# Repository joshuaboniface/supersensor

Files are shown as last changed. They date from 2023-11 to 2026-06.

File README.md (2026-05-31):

# SuperSensor v3.x

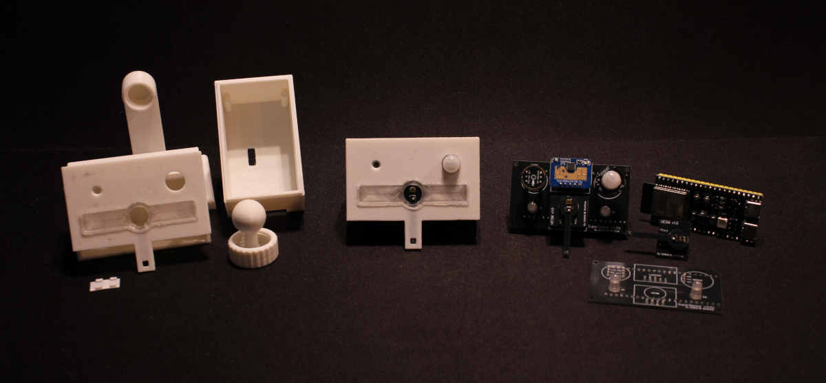
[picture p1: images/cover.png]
SuperSensor


The SuperSensor is a free-and-open-source multi-sensor array with voice control capabilities using ESPHome, designed for use with Home Assistant.

Inspired heavily by the EverythingSmartHome Everything Presence One sensor and the HomeAssistant "$13 Voice Assistant" project, its goals are to track human presence in a room using both millimetre-wave radar and passive infrared, provide voice control capabilities for Home Assistant Assist pipelines via a microphone and coloured feedback LEDs, and provide data on the room environment including temperature, humidity, VOC, eCO2, NOx, and light levels. It's based on the ESP32-S3 platform running ESPHome, providing plenty of power for all the demands of this sensor array.

If you want to automate your home and life with Home Assistant, the SuperSensor is the perfect tool for the job.

This branch is for version 3.x of the SuperSensor, the current version, based on the ESP32-S3 microcontroller and using our custom Unified Environment Sensor Module (UESM). For previous versions based on the ESP32 microcontroller, please see the [v2.x](https://github.com/joshuaboniface/supersensor/tree/v2.x) and [v1.x](https://github.com/joshuaboniface/supersensor/tree/v1.x) branches. Users new to the project should use v3.x exclusively as it has numerous improvements over the previous versions, even though it is more complicated to build.

For more information, please see the following:

 * The [blog post on v3.0](https://www.boniface.me/posts/the-supersensor-3.0)
 * The [introduction video]()
 * The PCB design details [in `board/`](board/) and on [OSHWLab](https://oshwlab.com/joshuaboniface/supersensor-3-0)
 * The case design details [in `case/`](case/) and on [TinkerCAD](https://www.tinkercad.com/things/gx66mJQMgR6)
 * Calibration and configuration instructions [in `configuration/`](configuration/).

## Table of Contents

* [Overview](#overview)
   * [Core Components](#core-components)
   * [Software](#software)
* [PCB Design & DIY](#pcb-design--diy)
   * [UESM Parts List](#uesm-parts-list)
   * [SuperSensor Parts List](#supersensor-parts-list)
   * [Case/Enclosure](#caseenclosure)
   * [Adopting, Calibrating, and Configuring](#adopting-calibrating-and-configuring)
* [More Information](#more-information)
   * [Contributing](#contributing)

# Overview

## Core Components

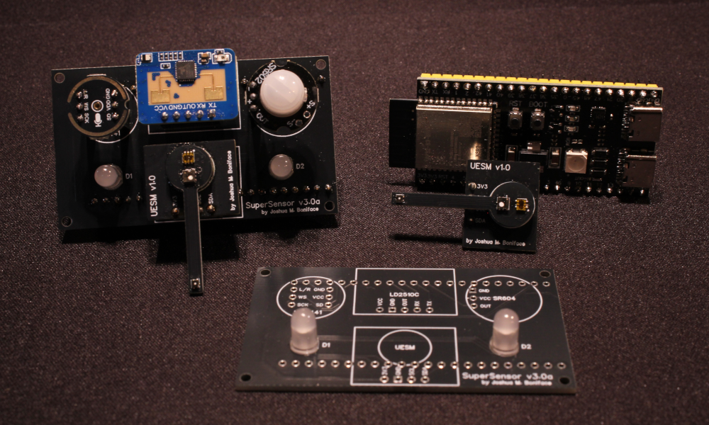
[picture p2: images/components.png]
Components


### ESP32-S3-N8R2 microcontroller

This microcontroller provides the "brains" of the SuperSensor. As the latest generation of high-performance microcontrollers in the ESP32 family, it contains many improvements on previous ESP32 chips, including better machine learning support for local OpenWakeWord detection, more memory for the Assist pipelines (fixing crashes in v2.x), and a nicer pin layout including better power delivery. We use unofficial modules here for cost savings, and the N8R2 configuration with additional flash and PSRAM is required due to specific configurations and pin assignments in the final design.

### HiLink HLK-LD2410C 24GHz radar module

This millimetre-wave radar module provides an excellent balance between form-factor, cost, reliability, and performance. It is capable of detecting human-like motion from 1-6m with configurable distance gates, and has served us reliably through all 3 versions of the SuperSensor.

### SR602 PIR module

This passive infrared module provides excellent value and a compatable form-factor for our purposes. It is capable of rapidly detecting human motion in front of the sensor.

### Custom "UESM" module

The custom-designed Unified Environment Sensor Module, or UESM, is the heart of the SuperSensor v3.x, combining 3 discrete environmental sensors into one convenient module.

* An AMS TSL2591 ambient light sensor providing both visible and infrared light levels, giving both an additional "presence" indicator and a general light level for automations.

* A Sensirion SGP41 VOC and NOx level sensor, giving air quality information with compensation from the SHT45.

* A Sensirion SHT45 high-precision temperature and humidity sensor, giving both these values as well as several computed values like absolute humidity and dew point, and placed on a descender to isolate it from the heat of the other components.

These 3 components are combined on a custom module featuring 3 stacked PCB levels. The pin connections and passive power circuitry (bottom, 3.3v **only**) are on the lower level, in a standard rectangular form factor on par with a standalone TSL2591 module. On top is a circular 1 cm diameter spacer PCB for added height, and finally above that is another circular 1 cm diameter PCB containing the 3 actual sensor modules on the top surface.

This design was created specifically due to the challenges of the SuperSensor: the sensors must be well outside the case and into the ambient environment to properly detect the environmental conditions and avoid being excessively influenced by the other components; and due to our case design, they must protrude a fair amount above the other sensor modules in the upper layer without obstructions from passive components, pins etc. affecting the top cover. The final sensor design provides a great solution to both problems.

### INMP441 MEMS microphone module

This basic microphone provides our voice interface input, listening for wake words continuously (local-only) as well as commands after detection (external processing to STT). The INMP441 is electrically simple and easy to use while still offering excellent performance.

### RGB LEDs x2

A pair of RGB LEDs provide active feedback for the voice interface, as well as for presence detection. When voice is idle and presence is detected, the LEDs will glow slightly (configurable); when voice control is active, the LEDs cycle through various colours to indicate status - blue for listening, cyan for processing, green for success, and red for failure (the latter two as reported by Home Assistant).

## Case/Enclosure

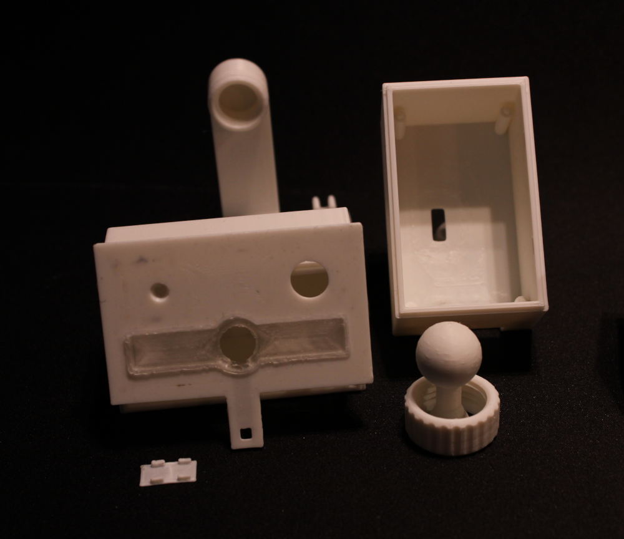
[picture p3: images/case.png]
Case


The case/enclosure for the SuperSensor is also provided under a compatible free-and-open-source license (Creative Commons Attribution-ShareAlike 4.0). It is mostly self-designed but contains elements from [Nikolay "darkfrei"'s Universal Ball Joint design](https://www.thingiverse.com/thing:6804839) for the mounting components.

The design features several main parts with individual STL files in [the `case/` directory](case/):

* a body with standoffs to hold the assembled PCB with USB connections on the right side (facing the sensor)
* a cover with holes for the microphone, the PIR cover, and the LED insert, with a descender to cover the UESM SHT45 sensor including a small back plate
* an LED insert diffuser with a hole for the UESM
* a wall-mount assembly featuring two 45+° ball joints for full articulation, with 3 separate mount point options (3M Command™ strip/double-sided tape, cable ties, or M4/#6 screws)
* a table-mount assembly featuring one 45+° ball joint and a flat bottom including cutouts for 4 ~13mm rubber anti-slip feet

For more details including important printing, assembly, and positioning guides, see the README in that directory.

## Software

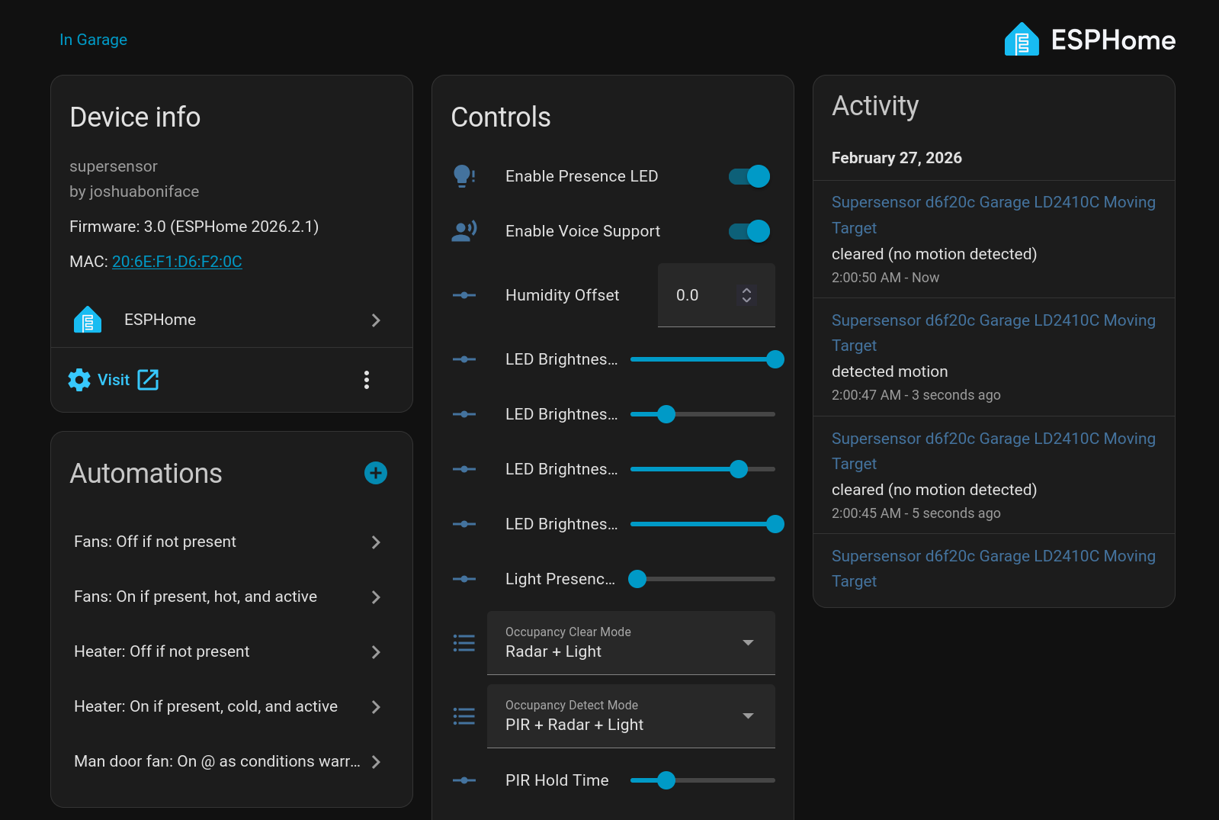
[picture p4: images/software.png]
Software


The SuperSensor runs ESPHome, as this provides an excellent interface into Home Assistant as well as a standalone Web server, with excellent OTA update support and simple provisioning and onboarding. The config is provided, via this repo, as a standard package allowing seamless updates as new features, bugfixes, or other changes are developed, once the device is adopted into the ESPHome Companion module in Home Assistant.

The software stack and output sensors can be nicely mapped to the above hardware components, with some additional glue functionality added as well:

* A unified "occupancy" presence detection system, with configurable inbound and outbound detection options selecting from the radar, PIR, and light level sensors in various possible combinations. This provides a user with a great variety of options for controlling presence detection and clearing, as well as a single unified sensor for use in automations. On inbound, the occupancy is triggered by a logical "and" of the configured sensors (all must fire), while outbound is triggered by a logical "or" (any one clearing clears the occupancy); this allows for the configuration of very "safe" detection in both directions if needed, or simple fallback to a single mechanism in either direction.

* A "room health" sensor system, which provides a fully configurable merging of the various temperature, humidity, and air quality sensors into a single numerical (%) or text sensor providing the relative "health" or comfort level of a room, with 100% representing a perfect environment. All the parameters are configurable as required, to set exactly the specifications you desire in your room. For more details, see [the Room Health section of the configuration README](/configuration#room-health).

* The voice pipeline leverages Micro Wake Word with a decent number of wake words, including all the stock ESPHome/Home Assistant options and several choice inclusions from other repositories. The wake word is selectable at runtime, along with many other parameters allowing fine adjustment of the voice control to suit your needs. The voice control functionality can also be fully disabled with a single switch should this be desired.

* The LD2410C configuration is fully exposed, allowing easy tweaks of the parameters from within Home Assistant or ESPHome, including initial empty room calibration.

* The SHT45 and SGP41 values are averaged using a sliding window over 1 minute (15s sammples with 4 samples in a window) to balance long-term trends against short-term spikes.

A standard concept we've followed is that "if it can be configured at runtime, it should be exposed", so as much as possible about the sensor behaviour is configurable, giving the user maximum flexibility.

The entire software stack is licensed under the GNU GPL v3, qualifying fully as free-and-open-source software.

# PCB Design & DIY

The full hardware description is provided here, including all components and PCB designs, under a compatible free-and-open-source license (Creative Commons Attribution+ShareAlike 4.0).

The SuperSensor features 4 printed circuit boards: the main backplane board that connects the ESP32, sensor boards, LEDs, and their passive components; and 3 boards making up the UESM module (base, spacer, and top). Schematics and board definitions for EasyEDA can be found in [the `board/` directory](board/).

Below are full parts lists, along with pricing and links to the exact suppliers used to assemble our own sensors. PCB IDs are provided for easy reference; note that these IDs are for the [combined schematic](/board/schematic.svg) of both the UESM and main board and increment accordingly.

## UESM Parts List

**Note:** All prices are $CAD, as of late November 2025, excluding shipping, sales, and bulk discounts beyond those indicated.

**Note:** For AliExpress item links marked `*`, ensure you select the correct device; multiple different models share the page.

| Qty | PCB ID(s) | Component | Cost | Links |
|---|---|---|---|---|
| 1 | N/A | PCB - "UESM Base" | $0.21 ($5.20/25) | [EasyEDA/JLCPCB](/board/pcb-uesm-base.easyeda.json) |
| 1 | N/A | PCB - "UESM Spacer" | $0.22 ($5.30/25) | [EasyEDA/JLCPCB](/board/pcb-uesm-spacer.easyeda.json) |
| 1 | N/A | PCB - "UESM Top" | $0.22 ($5.30/25) | [EasyEDA/JLCPCB](/board/pcb-uesm-top.easyeda.json) |
| 1 | U1 | Sensirion SHT45-AD1F-R2 | $9.37 | [DigiKey.ca](https://www.digikey.ca/en/products/detail/sensirion-ag/SHT45-AD1F-R2/17180856) |
| 1 | U2 | Sensirion SGP41-D-R4 | $13.00 | [DigiKey.ca](https://www.digikey.ca/en/products/detail/sensirion-ag/SGP41-D-R4/15652788) |
| 1 | U3 | AMS TSL25911FNCT-ND | $2.65 | [DigiKey.ca](https://www.digikey.ca/en/products/detail/ams-osram-usa-inc/TSL25911FN/4162547) |
| 2 | R1, R2 | CR1206-FX-4701ELFCT-ND (4.7KΩ 1% 1/4W 1206) | $0.16 | [DigiKey.ca](https://www.digikey.ca/en/products/detail/bourns-inc/CR1206-FX-4701ELF/2563072) |
| 1 | R3 | CR1206-FX-10R0ELFCT-ND (10Ω 1% 1/4W 1206) | $0.16 | [DigiKey.ca](https://www.digikey.ca/en/products/detail/bourns-inc/CR1206-FX-10R0ELF/2562695) |
| 1 | R4 | CR0603-JW-104ELFCT-ND (100KΩ 5% 1/10W 0603) | $0.16 | [DigiKey.ca](https://www.digikey.ca/en/products/detail/bourns-inc/CR0603-JW-104ELF/2345098) |
| 1 | C1 | 399-C0805C106K8PACTUCT-ND (10μF 10V X5R 0805)  | $0.19 | [DigiKey.ca](https://www.digikey.ca/en/products/detail/kemet/C0805C106K8PACTU/1090830) |
| 1 | C2 | 399-C0805C104K5RACTUCT-ND (0.1μF 50V X7R 0805) | $0.12 | [DigiKey.ca](https://www.digikey.ca/en/products/detail/kemet/C0805C104K5RACTU/411169) |
| 1 | C3 | 399-C0805C105K3RACTUCT-ND (1μF 50V X7R 0805) | $0.18 | [DigiKey.ca](https://www.digikey.ca/en/products/detail/kemet/C0805C105K3RACTU/2211765) |
| 1 | H1 | 2.54mm 1x4 male header | $0.05 | [AliExpress](https://www.aliexpress.com/item/4000988113226.html)* |
| **T** | | | **$26.85** | *plus tools, solder, etc.* |

## SuperSensor Parts List

**Note:** All prices are $CAD, as of early December 2025, excluding shipping and bulk discounts.

**Note:** For AliExpress item links marked `*`, ensure you select the correct device; multiple different models share the page.

| Qty | PCB ID(s) | Component | Cost | Links |
|---|---|---|---|---|
| 1 | N/A | PCB - "SuperSensor" | $0.35 ($8.70/25) | [EasyEDA/JLCPCB](/board/pcb-supersensor.easyeda.json) |
| 1 | U4 | ESP32-S3-1-N8R2, unsoldered | $5.49 | [AliExpress](https://www.aliexpress.com/item/1005010056064272.html)* |
| 1 | U5 | UESM, unassembled | $26.85 | *see above for individual component prices* |
| 1 | U6 | Hornaxys SR602 PIR | $1.13 ($5.65/5) | [AliExpress](https://www.aliexpress.com/item/1005006533504953.html) |
| 1 | U7 | HiLink HLK-LD2410C-P | $4.89 | [AliExpress](https://www.aliexpress.com/item/1005006000579211.html)* |
| 1 | U8 | INMP441 | $5.25 | [AliExpress](https://www.aliexpress.com/item/1005010338533932.html) |
| 2 | D1, D2 | Cleiscry 5mm diffused common-cathode RGB LED | $0.09 ($9.12/100) | [Amazon.ca](https://www.amazon.ca/dp/B09Y8M2PKS) |
| 2 | R5, R6 | 118-CR1206-FX-33R0ELFCT-ND (33Ω 1% 1/4W 1206) | $0.16 | [DigiKey.ca](https://www.digikey.ca/en/products/detail/bourns-inc/CR1206-FX-33R0ELF/2562981) |
| 1 | C4 | 399-C0805C104K5RACTUCT-ND (0.1μF 50V X7R 0805) | $0.12 | [DigiKey.ca](https://www.digikey.ca/en/products/detail/kemet/C0805C104K5RACTU/411169) |
| 3 | N/A | 2.54mm 1x3 female header | $0.23 ($2.25/10) | [AliExpress](https://www.aliexpress.com/item/4001198421663.html)* |
| 1 | N/A | 2.54mm 1x4 female header | $0.21 ($2.12/10) | [AliExpress](https://www.aliexpress.com/item/4001198421663.html)* |
| 1 | N/A | 2.54mm 1x5 female header | $0.23 ($2.32/10) | [AliExpress](https://www.aliexpress.com/item/4001198421663.html)* |
| 2 | N/A | 2.54mm 1x22 female header | $0.31 ($3.14/10) | [AliExpress](https://www.aliexpress.com/item/4001198421663.html)* |
| **T** | | | **$46.33** | *plus tools, solder, etc.* |

**Note:** For the ESP32-S3-N8R2-DevKitC-1 to function properly as a 5V power source for other components (i.e. the LD2410C and SR602) within the SuperSensor, you must bridge the "In-Out" jumper on the front of the PCB near pins 11 and 12. This bypasses a protection diode preventing the 5Vin pin from backfeeding power into the circuit, but also enables us to get an actual 5V off the pin.

## Adopting, Calibrating, and Configuring

To adopt a SuperSensor into your Home Assistant:

1. Power on the device.
2. Using your smartphone, connect to the open wireless access point named `supersensor-XXXXXX`, where `XXXXXX` is the 6-character SuperSensor ID.
3. Follow the captive portal signon page and enter your WiFi credentials; the SuperSensor will connect to your WiFi network.
4. Navigate to the ESPHome Builder tab in Home Assistant. The SuperSensor should become visible as a discovered device.
5. Click "Take Control", and install the generated configuration. Once finished, edit the configuration and copy the API encryption key.
   **Note:** We recommend NOT setting a "Friendly Name" at this time to ensure that entity IDs do not contain the "friendly name" (e.g. `supersensor_XXXXXX_my_name_sht45...` instead of `supersensor_XXXXXX_sht45...`).
6. Navigate to Settings -> Devices & Services; the SuperSensor should appear at the top; click "Add", then when prompted enter the API key. The device should now be visible in your system.
7. You can now customize the name suffix in the ESPHome Builder configuration by adding to the "Friendly Name" field, e.g. "SuperSensor XXXXXX Living Room", to give it a clearer name.
8. All entities should be available in the form `<type>.supersensor_XXXXXX_<name>` within your automations and cards.
9. If desired, you can obtain a "Location Name" entity by creating a template sensor helper with the following details:
   * Name: `SuperSensor XXXXXX Device Location Name`
   * State: `{{ device_attr('binary_sensor.supersensor_XXXXXX_supersensor_occupancy', 'name')|replace('Supersensor XXXXXX ', '') }}`
   * Device: `SuperSensor XXXXXX ...`

The SuperSensor provides a very wide array of configurable options. We also provide a convenient templatable dashboard which neatly organizies the various configuration options and sensor outputs for easy display and configuration of multiple SuperSensors in your Home Assistant configuration.

The SuperSensor requires [two main pieces of calibration](configuration#calibration) before being truly usable:

* Calibration of the HLK-LD2410C to properly detect presence in a room.

* Calibration of the SHT45 temperature sensor. The default Temperature Offset value of `-2.0` should be accurate enough for most users, though a SuperSensor in a steady airstream may need a higher (closer to `0.0`) value.

In addition, we also provide a [helpful, templatable Dashboard](configuration#dashboard) for all your SuperSensors leveraging the [decluterring card from HACS](https://github.com/custom-cards/decluttering-card).

For more details on these options and steps, please see [the `configuration/` directory](configuration/).

# More Information

For more information please feel free to reach out, or open an issue.

## Contributing

If you wish to contribute to the SuperSensor project, please open a pull request in this repository. All pull requests will be carefully reviewed before inclusion, as we are extremely selective about what we modify.

Please ensure you target the correct branch(es) for your changes. Currently we are supporting both `v2.x` and `v3.x` in software, while `v1.x` is deprecated, and there is no `master`/`main` branch. This support of both `v2.x` and `v3.x` means a 1-to-1 correlation of functionality between those two versions, so any PR to one will be back- or forward-ported to the other, and your changes(s) must be compatable with both.

Any changes must be **globally applicable to all users** of the project; if you wish to maintain your own customizations that are only applicable for yourself, please fork the project and adjust your package import URL accordingly.

"AI" (LLM) contributions are not prohibited, but you - a human - **must** at least review, reformat, and test the changes yourself before submitting them. Obviously pure-LLM-generated PRs that do not function, mangle formatting or functionality, or otherwise clearly have no human review will be rejected with prejudice. This extends to the PR body itself: write in your own words, not the output of an LLM, and if you can't concisely sumarize the changes yourself, then we're not interested in them.

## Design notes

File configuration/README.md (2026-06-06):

# SuperSensor v3.x Calibration & Configuration

This page details the calibration steps for a SuperSensor v3.x, as well as all the available configurable options and sensor entities. It can be used as a standard reference both for initial deployments and future tweaks or modifications to the configuration.

* [Calibration](#calibration)
   * [HLK-LD2410C Radar Sensor](#hlk-ld2410C-radar-sensor)
   * [SHT45 Temperature Sensor](#sht45-temperature-sensor)
* [Dashboard](#dashboard)
* [Configuration Entities](#configuration)
   * [Presence](#presence)
   * [Environment](#environment)
   * [Voice Assistant & Response](#voice-assistant--response)
   * [LD2410C Radar](#ld2410c-radar)
* [Sensor Entities](#sensors)
   * [Overall/Device Sensors](#overalldevice-sensors)
   * [Environmental Sensors](#environmental-sensors)
   * [Light Sensors](#light-sensors)
   * [Radar Sensors](#radar-sensors)
   * [PIR Sensors](#pir-sensors)

## Calibration

The SuperSensor requires two main pieces of calibration before being truly usable: configuration of the HLK-LD2410C radar sensor, and configuration of the "Temperature Offset" value for the SHT45 temperature/humidity sensor.

### HLK-LD2410C Radar Sensor

The SuperSensor features the ability to automatically calibrate the HLK-LD2410C from within Home Assistant. This can avoid the need for an external app, though advanced users may still wish to use the "HLKRadarTool" app ([Google Play](https://play.google.com/store/apps/details?id=com.hlk.hlkradartool)/[Apple AppStore](https://apps.apple.com/us/app/hlkradartool/id1638651152)) for more careful tweaking. We will not touch on the details of that app here, as there are other guides available from e.g. [DroneBot Workshop](https://dronebotworkshop.com/ld2410c-human-sensor/) and [Screek Workshop](https://screek.io/gen1) for those wishing to know more.

Without calibration, the default values of the HLK-LD2410C presence gates are likely not accurate for your room environment, which can result in missed triggers if they are not sensitive enough, or false triggers if they are too sensitive. This process will ensure your sensors are calibrated to a good baseline of known radar reflections in an empty room, from which you can slightly tweak the values for more accurate presence detection.

   **Note:** Keep in mind that due to its mode of operation, non-human objects in the detection range that move with roughly the frequency of human breating (0-5 Hz), such as fans, curtains, etc. will negatively affect the radar detection capabilities, triggering false detection. Take care to account for this in your placement of the sensor and during your calibration. The biggest culprits in our experience are ceiling fans and oscillating fans, as well as curtains blowing in the breeze by an open window. If you find this happening, adjust your triggering gates higher accordingly, or move the sensor so that they are outside of the main line of sight or in a distance gate you do not otherwise care about.

1. Enable the "LD2410C Engineering Mode" switch. This will activate the various "LD2410C GX Move/Still Energy" sensors to see individual gate activity.

2. Clear/clean the room of any moving objects, people, etc. that may interfere with the calibration. Exit the room yourself.

3. Press the "LD2410C Calibration" button. This will wait 10 seconds, then perform a 900 second (15 minute) base noise calibration routine on the HLK-LD2410C, then finally refresh the "LD2410C GX Move/Still Threshold" number values in ESPHome/Home Assistant and increment each of them by 2 for additional headroom. During this time, the "LD2410C Calibration Status" sensor will show the progress/state of the calibration.

4. Check the configured values for the various "LD2410C GX Move/Still Threshold" numbers. As noted, we automatically increase them by 2 from what the calibration reported, but you can also tweak them up or down further as required for your specific environment.

5. Check the behaviour by entering the room and observing the sensor outputs. Ensure that your standard movements and stationary locations adequately trigger the various gates and overall presence indication.

6. Adjust the "LD2410C Timeout" to provide a good timeout value for your environment; we tend to use somewhere from 30 to 90 seconds, though up to 300 seconds can be useful in places where occupants are stationary (sleeping, sitting for extended periods, etc.). Note that retriggers within this timeout will ensure occupancy remains active, so set this based on your expected use: it should be high enough to capture low-movement stationary situations like sleeping, while more active areas can do with lower values.

7. Continue to observe the "LD2410C GX Move/Still Energy" and overall occupancy sensors for a few days with the "LD2410C Engineering Mode" switch still on, to ensure that the sensor is behaving correctly. You may need to tweak the individual gate values further as time goes on and the environment changes.

7. Disable the "LD2410C Engineering Mode" switch or press the "LD2410C Restart" button to perform a clean reset. Your radar presence sensor is now configured. If you ever move the SuperSensor again, repeat this process to ensure accurate calibration in the new field of view.

### SHT45 Temperature Sensor

The SuperSensor exposes "Temperature Offset" (ΔT) and "[Relative] Humidity Offset" (ΔRH) calibration values which allow you to specify an offset to the raw SHT45 Temperature/Relative Humidity values. This is needed due to the heat produced by other components in the SuperSensor such as the ESP32 and the LD2510C affecting the SHT45 sensor, especially when enclosed in the case, as well as drift between individual sensors. These offset values are configurable in the range from -30°C to +10°C and -40% to +40%, respectively.

The SuperSensor has a default ΔT value of `-2.0`. This has been found through extensive testing to be reasonably accurate for most home environments and sufficiently accurate for useful automations, when using the SuperSensor with its included case. The default ΔRH value is `0.0`, as we have found most SHT45 sensors to be quite accurate here, though outliers exist and this can be useful for such sensors.

Note however that the ΔT can drift in steady airflow such as a direct fan airstream, due to additional cooling of the case (and thus, internal heat sources). In such cases, an offset closer to `0.0` might be warranted. Experiment with the sensor in your environment using an external reference temperature to be sure; if you need a reference, we recommend our [Microenv sensor solution](https://github.com/joshuaboniface/microenv) as it features the same sensors in a carefully calibrated configuration for optimal temperature accuracy. Avoid fretting too much about <1° of offset, as this can be an exercise in frustration (trust us); adjust this only when the conditions are persistent (e.g. you've mounted the SuperSensor over an air purifier that is always on).

## Dashboard

We provide a helpful dashboard which combines all the (relevant) sensors and configurations below into a single page, leveraging the [decluttering card from HACS](https://github.com/custom-cards/decluttering-card) to support multiple SuperSensors without much hassle.

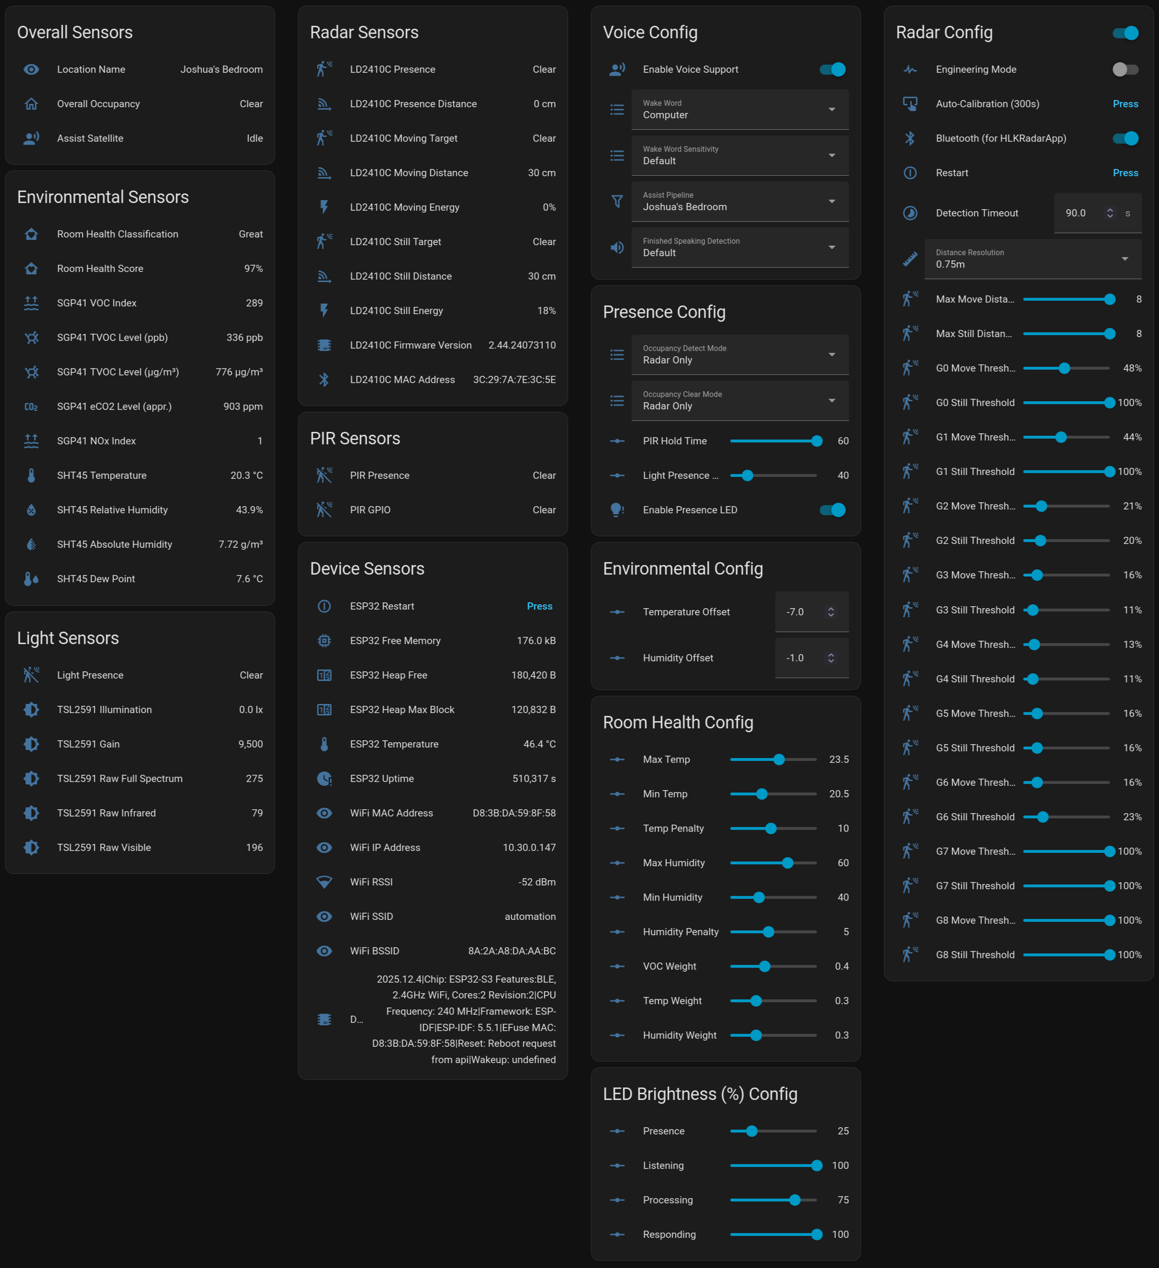
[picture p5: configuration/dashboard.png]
SuperSensor Dashboard


Add this to a new dashboard to begin, then add a section for each SuperSensor you wish to manage, replacing the `XXXXXX` and `YYYYYY` with your SuperSensor IDs.

```
###                                   ###
### Decluttering Template Definitions ###
###                                   ###
decluttering_templates:
  supersensor_overall:
    card:
      type: entities
      title: Overall Sensors
      entities:
        - entity: sensor.supersensor_[[supersensor_id]]_device_location_name
          name: Location Name
        - entity: binary_sensor.supersensor_[[supersensor_id]]_supersensor_occupancy
          name: Overall Occupancy
        - entity: assist_satellite.supersensor_[[supersensor_id]]_assist_satellite
          name: Assist Satellite
  supersensor_env:
    card:
      type: entities
      title: Environmental Sensors
      entities:
        - entity: sensor.supersensor_[[supersensor_id]]_room_health
          name: Room Health Classification
        - entity: sensor.supersensor_[[supersensor_id]]_room_health_score
          name: Room Health Score
        - entity: sensor.supersensor_[[supersensor_id]]_sgp41_voc_index
          name: SGP41 VOC Index
        - entity: sensor.supersensor_[[supersensor_id]]_sgp41_tvoc_ppb
          name: SGP41 TVOC Level (ppb)
        - entity: sensor.supersensor_[[supersensor_id]]_sgp41_tvoc_mg_m3
          name: SGP41 TVOC Level (µg/m³)
        - entity: sensor.supersensor_[[supersensor_id]]_sgp41_eco2_appr
          name: SGP41 eCO2 Level (appr.)
        - entity: sensor.supersensor_[[supersensor_id]]_sgp41_nox_index
          name: SGP41 NOx Index
        - entity: sensor.supersensor_[[supersensor_id]]_sht45_temperature
          name: SHT45 Temperature
        - entity: sensor.supersensor_[[supersensor_id]]_sht45_relative_humidity
          name: SHT45 Relative Humidity
        - entity: sensor.supersensor_[[supersensor_id]]_sht45_absolute_humidity
          name: SHT45 Absolute Humidity
        - entity: sensor.supersensor_[[supersensor_id]]_sht45_dew_point
          name: SHT45 Dew Point
  supersensor_light:
    card:
      type: entities
      title: Light Sensors
      entities:
        - entity: binary_sensor.supersensor_[[supersensor_id]]_light_presence
          name: Light Presence
        - entity: sensor.supersensor_[[supersensor_id]]_tsl2591_illumination
          name: TSL2591 Illumination
        - entity: sensor.supersensor_[[supersensor_id]]_tsl2591_gain
          name: TSL2591 Gain
        - entity: sensor.supersensor_[[supersensor_id]]_tsl2591_raw_full_spectrum
          name: TSL2591 Raw Full Spectrum
        - entity: sensor.supersensor_[[supersensor_id]]_tsl2591_raw_infrared
          name: TSL2591 Raw Infrared
        - entity: sensor.supersensor_[[supersensor_id]]_tsl2591_raw_visible
          name: TSL2591 Raw Visible
  supersensor_radar:
    card:
      type: entities
      title: Radar Sensors
      entities:
        - entity: binary_sensor.supersensor_[[supersensor_id]]_ld2410c_presence
          name: LD2410C Presence
        - entity: sensor.supersensor_[[supersensor_id]]_ld2410c_presence_distance
          name: LD2410C Presence Distance
        - entity: binary_sensor.supersensor_[[supersensor_id]]_ld2410c_moving_target
          name: LD2410C Moving Target
        - entity: sensor.supersensor_[[supersensor_id]]_ld2410c_moving_distance
          name: LD2410C Moving Distance
        - entity: sensor.supersensor_[[supersensor_id]]_ld2410c_move_energy
          name: LD2410C Moving Energy
        - entity: binary_sensor.supersensor_[[supersensor_id]]_ld2410c_still_target
          name: LD2410C Still Target
        - entity: sensor.supersensor_[[supersensor_id]]_ld2410c_still_distance
          name: LD2410C Still Distance
        - entity: sensor.supersensor_[[supersensor_id]]_ld2410c_still_energy
          name: LD2410C Still Energy
        - entity: sensor.supersensor_[[supersensor_id]]_ld2410c_firmware_version
          name: LD2410C Firmware Version
        - entity: sensor.supersensor_[[supersensor_id]]_ld2410c_mac_address
          name: LD2410C MAC Address
  supersensor_pir:
    card:
      type: entities
      title: PIR Sensors
      entities:
        - entity: binary_sensor.supersensor_[[supersensor_id]]_pir_presence
          name: PIR Presence
        - entity: binary_sensor.supersensor_[[supersensor_id]]_pir_gpio
          name: PIR GPIO
  supersensor_device:
    card:
      type: entities
      title: Device Sensors
      show_header_toggle: false
      entities:
        - entity: button.supersensor_[[supersensor_id]]_esp32_restart
          name: ESP32 Restart
        - entity: sensor.supersensor_[[supersensor_id]]_esp32_free_memory
          name: ESP32 Free Memory
        - entity: sensor.supersensor_[[supersensor_id]]_esp32_heap_free
          name: ESP32 Heap Free
        - entity: sensor.supersensor_[[supersensor_id]]_esp32_heap_max_block
          name: ESP32 Heap Max Block
        - entity: sensor.supersensor_[[supersensor_id]]_esp32_temperature
          name: ESP32 Temperature
        - entity: sensor.supersensor_[[supersensor_id]]_esp32_uptime
          name: ESP32 Uptime
        - entity: sensor.supersensor_[[supersensor_id]]_wifi_mac_address
          name: WiFi MAC Address
        - entity: sensor.supersensor_[[supersensor_id]]_wifi_ip_address
          name: WiFi IP Address
        - entity: sensor.supersensor_[[supersensor_id]]_wifi_rssi
          name: WiFi RSSI
        - entity: sensor.supersensor_[[supersensor_id]]_wifi_ssid
          name: WiFi SSID
        - entity: sensor.supersensor_[[supersensor_id]]_wifi_bssid
          name: WiFi BSSID
        - entity: sensor.supersensor_[[supersensor_id]]_device_info
          name: Device Info
  supersensor_voice_config:
    card:
      type: entities
      title: Voice Config
      entities:
        - entity: switch.supersensor_[[supersensor_id]]_enable_voice_support
          name: Enable Voice Support
        - entity: select.supersensor_[[supersensor_id]]_wake_word_selector
          name: Wake Word
        - entity: select.supersensor_[[supersensor_id]]_wake_word_sensitivity
          name: Wake Word Sensitivity
        - entity: select.supersensor_[[supersensor_id]]_assistant
          name: Assist Pipeline
        - entity: select.supersensor_[[supersensor_id]]_finished_speaking_detection
          name: Finished Speaking Detection
  supersensor_presence_config:
    card:
      type: entities
      title: Presence Config
      entities:
        - entity: select.supersensor_[[supersensor_id]]_occupancy_detect_mode
          name: Occupancy Detect Mode
        - entity: select.supersensor_[[supersensor_id]]_occupancy_clear_mode
          name: Occupancy Clear Mode
        - entity: number.supersensor_[[supersensor_id]]_pir_hold_time
          name: PIR Hold Time
        - entity: number.supersensor_[[supersensor_id]]_light_presence_threshold
          name: Light Presence Threshold
        - entity: switch.supersensor_[[supersensor_id]]_enable_presence_led
          name: Enable Presence LED
  supersensor_env_config:
    card:
      type: entities
      title: Environmental Config
      entities:
        - entity: number.supersensor_[[supersensor_id]]_temperature_offset
          name: Temperature Offset
        - entity: number.supersensor_[[supersensor_id]]_humidity_offset
          name: Humidity Offset
  supersensor_room_health_config:
    card:
      type: entities
      title: Room Health Config
      entities:
        - entity: number.supersensor_[[supersensor_id]]_room_health_max_temperature
          name: Max Temp
        - entity: number.supersensor_[[supersensor_id]]_room_health_min_temperature
          name: Min Temp
        - entity: >-
            number.supersensor_[[supersensor_id]]_room_health_temperature_penalty
          name: Temp Penalty
        - entity: number.supersensor_[[supersensor_id]]_room_health_max_humidity
          name: Max Humidity
        - entity: number.supersensor_[[supersensor_id]]_room_health_min_humidity
          name: Min Humidity
        - entity: number.supersensor_[[supersensor_id]]_room_health_humidity_penalty
          name: Humidity Penalty
        - entity: number.supersensor_[[supersensor_id]]_room_health_voc_weight
          name: VOC Weight
        - entity: number.supersensor_[[supersensor_id]]_room_health_temperature_weight
          name: Temp Weight
        - entity: number.supersensor_[[supersensor_id]]_room_health_humidity_weight
          name: Humidity Weight
  supersensor_led_config:
    card:
      type: entities
      title: LED Brightness (%) Config
      entities:
        - entity: number.supersensor_[[supersensor_id]]_led_brightness_presence
          name: Presence
        - entity: number.supersensor_[[supersensor_id]]_led_brightness_listening
          name: Listening
        - entity: number.supersensor_[[supersensor_id]]_led_brightness_processing
          name: Processing
        - entity: number.supersensor_[[supersensor_id]]_led_brightness_responding
          name: Responding
  supersensor_radar_config:
    card:
      type: entities
      title: Radar Config
      entities:
        - entity: switch.supersensor_[[supersensor_id]]_ld2410c_engineering_mode
          name: Engineering Mode
        - entity: switch.supersensor_[[supersensor_id]]_ld2410c_bluetooth
          name: LD2410C Bluetooth
        - entity: button.supersensor_[[supersensor_id]]_ld2410c_restart
          name: LD2410C Restart
        - entity: number.supersensor_[[supersensor_id]]_ld2410c_timeout
          name: Timeout
        - entity: select.supersensor_[[supersensor_id]]_ld2410c_distance_resolution
          name: Distance Resolution
        - entity: number.supersensor_[[supersensor_id]]_ld2410c_max_move_distance_gate
          name: Max Move Distance Gate
        - entity: >-
            number.supersensor_[[supersensor_id]]_ld2410c_max_still_distance_gate
          name: Max Still Distance Gate
        - entity: number.supersensor_[[supersensor_id]]_ld2410c_g0_move_threshold
          name: G0 Move Threshold
        - entity: number.supersensor_[[supersensor_id]]_ld2410c_g0_still_threshold
          name: G0 Still Threshold
        - entity: number.supersensor_[[supersensor_id]]_ld2410c_g1_move_threshold
          name: G1 Move Threshold
        - entity: number.supersensor_[[supersensor_id]]_ld2410c_g1_still_threshold
          name: G1 Still Threshold
        - entity: number.supersensor_[[supersensor_id]]_ld2410c_g2_move_threshold
          name: G2 Move Threshold
        - entity: number.supersensor_[[supersensor_id]]_ld2410c_g2_still_threshold
          name: G2 Still Threshold
        - entity: number.supersensor_[[supersensor_id]]_ld2410c_g3_move_threshold
          name: G3 Move Threshold
        - entity: number.supersensor_[[supersensor_id]]_ld2410c_g3_still_threshold
          name: G3 Still Threshold
        - entity: number.supersensor_[[supersensor_id]]_ld2410c_g4_move_threshold
          name: G4 Move Threshold
        - entity: number.supersensor_[[supersensor_id]]_ld2410c_g4_still_threshold
          name: G4 Still Threshold
        - entity: number.supersensor_[[supersensor_id]]_ld2410c_g5_move_threshold
          name: G5 Move Threshold
        - entity: number.supersensor_[[supersensor_id]]_ld2410c_g5_still_threshold
          name: G5 Still Threshold
        - entity: number.supersensor_[[supersensor_id]]_ld2410c_g6_move_threshold
          name: G6 Move Threshold
        - entity: number.supersensor_[[supersensor_id]]_ld2410c_g6_still_threshold
          name: G6 Still Threshold
        - entity: number.supersensor_[[supersensor_id]]_ld2410c_g7_move_threshold
          name: G7 Move Threshold
        - entity: number.supersensor_[[supersensor_id]]_ld2410c_g7_still_threshold
          name: G7 Still Threshold
        - entity: number.supersensor_[[supersensor_id]]_ld2410c_g8_move_threshold
          name: G8 Move Threshold
        - entity: number.supersensor_[[supersensor_id]]_ld2410c_g8_still_threshold
          name: G8 Still Threshold

views:

  ###                           ###
  ### FIRST EXAMPLE SUPERSENSOR ###
  ###                           ###
  - type: sections
    title: Bedroom
    icon: mdi:bed
    path: bedroom
    max_columns: 4
    cards: []
    sections:
      - type: grid
        cards:
          - type: custom:decluttering-card
            template: supersensor_overall
            variables:
              - supersensor_id: XXXXXX
          - type: custom:decluttering-card
            template: supersensor_env
            variables:
              - supersensor_id: XXXXXX
          - type: custom:decluttering-card
            template: supersensor_light
            variables:
              - supersensor_id: XXXXXX
      - type: grid
        cards:
          - type: custom:decluttering-card
            template: supersensor_radar
            variables:
              - supersensor_id: XXXXXX
          - type: custom:decluttering-card
            template: supersensor_pir
            variables:
              - supersensor_id: XXXXXX
          - type: custom:decluttering-card
            template: supersensor_device
            variables:
              - supersensor_id: XXXXXX
      - type: grid
        cards:
          - type: custom:decluttering-card
            template: supersensor_voice_config
            variables:
              - supersensor_id: XXXXXX
          - type: custom:decluttering-card
            template: supersensor_presence_config
            variables:
              - supersensor_id: XXXXXX
          - type: custom:decluttering-card
            template: supersensor_env_config
            variables:
              - supersensor_id: XXXXXX
          - type: custom:decluttering-card
            template: supersensor_room_health_config
            variables:
              - supersensor_id: XXXXXX
          - type: custom:decluttering-card
            template: supersensor_led_config
            variables:
              - supersensor_id: XXXXXX
      - type: grid
        cards:
          - type: custom:decluttering-card
            template: supersensor_radar_config
            variables:
              - supersensor_id: XXXXXX

  ###                            ###
  ### SECOND EXAMPLE SUPERSENSOR ###
  ###                            ###
  - type: sections
    title: Living Room
    icon: mdi:sofa
    path: living-room
    max_columns: 4
    cards: []
    sections:
      - type: grid
        cards:
          - type: custom:decluttering-card
            template: supersensor_overall
            variables:
              - supersensor_id: YYYYYY
          - type: custom:decluttering-card
            template: supersensor_env
            variables:
              - supersensor_id: YYYYYY
          - type: custom:decluttering-card
            template: supersensor_light
            variables:
              - supersensor_id: YYYYYY
      - type: grid
        cards:
          - type: custom:decluttering-card
            template: supersensor_radar
            variables:
              - supersensor_id: YYYYYY
          - type: custom:decluttering-card
            template: supersensor_pir
            variables:
              - supersensor_id: YYYYYY
          - type: custom:decluttering-card
            template: supersensor_device
            variables:
              - supersensor_id: YYYYYY
      - type: grid
        cards:
          - type: custom:decluttering-card
            template: supersensor_voice_config
            variables:
              - supersensor_id: YYYYYY
          - type: custom:decluttering-card
            template: supersensor_presence_config
            variables:
              - supersensor_id: YYYYYY
          - type: custom:decluttering-card
            template: supersensor_env_config
            variables:
              - supersensor_id: YYYYYY
          - type: custom:decluttering-card
            template: supersensor_room_health_config
            variables:
              - supersensor_id: YYYYYY
          - type: custom:decluttering-card
            template: supersensor_led_config
            variables:
              - supersensor_id: YYYYYY
      - type: grid
        cards:
          - type: custom:decluttering-card
            template: supersensor_radar_config
            variables:
              - supersensor_id: YYYYYY

  ###                            ###
  ### ADD MORE SUPERSENSORS HERE ###
  ###                            ###
```

## Configuration

The SuperSensor follows a philosophy of exposing as much configuration as possible via ESPHome, to permit users to adjust any available parametre to suit their needs. This section provides an exhaustive list of the available configurable settings, organized into broad categories based on logical groupings, rather than how they are displayed in the device UX in Home Assistant.

### Presence

#### Enable Presence LED

* Entity schema: `switch.supersensor_XXXXXX_enable_presence_led`
* Default value: `On`
* Range/values: `On`/`Off`

Controls whether the LEDs glow whenever `SuperSensor Occupancy` is `Detected`.

See also: [LED Brightness %: Presence](#led-brightness--presence)

#### Enable Voice Support

* Entity schema: `switch.supersensor_XXXXXX_enable_voice_support`
* Default value: `On`
* Range/values: `On`/`Off`

Controls the internal MicroWakeWord and Voice Assistant subsystem, which may be fully disabled by setting this to Off. Can also function as an internal Voice Assistant restart by toggling Off and then On again.

#### Light Presence Threshold

* Entity schema: `number.supersensor_XXXXXX_light_presence_threshold`
* Default value: `30`
* Range/values: `0` to `200`, `5` step

Controls the TLS2591 light level, in lux, which triggers an `Occupied` state for the Light Occupancy sensor.

See also: [Occupancy Detect Mode](#occupancy-detect-mode), [Occupancy Clear Mode](#occupancy-clear-mode)

#### PIR Hold Time

* Entity schema: `number.supersensor_XXXXXX_pir_hold_time`
* Default value: `15`
* Range/values: `0` to `60`, `5` step

Controls the time the PIR Occupancy sensor is held after a PIR GPIO trigger, in seconds. Further triggers during this time extend the hold. A value of `0` represents "As long as the GPIO is held" which is usually ~2.5 seconds.

#### Occupancy Detect Mode

* Entity schema: `select.supersensor_XXXXXX_occupancy_detect_mode`
* Default value: `None`
* Range/values: `PIR + Radar + Light`, `PIR + Radar`, `PIR + Light`, `Radar + Light`, `PIR Only`, `Radar Only`, `Light Only`, `None`

Controls the sensors that trigger an Occupied state for the SuperSensor Occupancy sensor. For values with multiple triggers, a logical `AND` of the values is assumed i.e. if all of the components trigger, the overall sensor triggers. 

> A unified "occupancy" presence detection system, with configurable inbound and outbound detection options selecting from the radar, PIR, and light level sensors in various possible combinations. This provides a user with a great variety of options for controlling presence detection and clearing, as well as a single unified sensor for use in automations. On inbound, the occupancy is triggered by a logical "and" of the configured sensors (all must fire), while outbound is triggered by a logical "or" (any one clearing clears the occupancy); this allows for the configuration of very "safe" detection in both directions if needed, or simple fallback to a single mechanism in either direction.

#### Occupancy Clear Mode

* Entity schema: `select.supersensor_XXXXXX_occupancy_clear_mode`
* Default value: `None`
* Range/values: `PIR + Radar + Light`, `PIR + Radar`, `PIR + Light`, `Radar + Light`, `PIR Only`, `Radar Only`, `Light Only`, `None`

Controls the sensors that trigger a Clear state for the SuperSensor Occupancy sensor. For values with multiple triggers, a logical `OR` of the values is assumed i.e. if any one of the components clears, the overall sensor clears.

> A unified "occupancy" presence detection system, with configurable inbound and outbound detection options selecting from the radar, PIR, and light level sensors in various possible combinations. This provides a user with a great variety of options for controlling presence detection and clearing, as well as a single unified sensor for use in automations. On inbound, the occupancy is triggered by a logical "and" of the configured sensors (all must fire), while outbound is triggered by a logical "or" (any one clearing clears the occupancy); this allows for the configuration of very "safe" detection in both directions if needed, or simple fallback to a single mechanism in either direction.

### Environment

#### Temperature Offset

* Entity schema: `number.supersensor_XXXXXX_temperature_offset`
* Default value: `-2.0` (based on extensive testing)
* Range/values: `-20.0` to `+10.0`, `0.1` step

Sets an offset of the detected SHT45 temperature value. Useful to calibrate the temperature value if it is significantly off.

As noted in the [SHT45 calibration section above](#sht45-temperature-sensor), the default value is `-2.0` to account for internal heating from the other components, and may require changing if the sensor is placed in steady airflow.

#### Humidity Offset

* Entity schema: `number.supersensor_XXXXXX_humidity_offset`
* Default value: `0.0`
* Range/values: `-50.0` to `+50.0`, `0.1` step

Sets an offset of the detected SHT45 humidity value. Useful to calibrate the humidity value if it is significantly off.

**Note:** This setting should usually be left at `0.0` unless you have a laboratory-grade hygrometre available to calibrate it. The SuperSensor also features internal recalibration of the SHT45 humidity value based on the above temperature offset.

### Room Health

Room Health is a custom metric provided by the SuperSensor which aggregates the temperature, humidity, and VOC levels into a single metric for room comfort/habitability on a scale of 0-100%. 100% represents an ideal room, 90% and above represents a habitable space, values below 90% represent gradually increasing states of unpleasentness, and 0% represents, approximately, Saturn's moon Titan (or similar). You can use these options to tweak exactly what contributes to this value and by how much, in order to tweak it for your own environment and preferences.

The room health score is calculated by first generating a 0-100% score for each of the 3 components (temperature, humidity, and VOC level) based on the values provided, and then combining these with the weights into a single 0-100% score. For example, if temperature scores 90%, humidity scores 100%, and VOC level scores 100%, with weights of 0.3, 0.3, and 0.4 (respectively, and always totaling 1.0), the resulting room health score will be:

```
(90 * 0.3) + (100 * 0.3) + (100 * 0.4) = 97%
```

If we instead weight temperature higher at 0.5 (and humidity and VOCs at 0.25), the result would be:

```
(90 * 0.5) + (100 * 0.25) + (100 * 0.25) = 95%
```

Thus, adjusting the individual component thresholds and penalties controls how much deviation of that component affects the total, and adjusting the weights controls how much each component contributs to the overall score. A weight of 0.0 would completely eliminate the effect of a given component from the score.

#### Room Health Min Temperature

* Entity schema: `number.supersensor_XXXXXX_room_health_min_temperature`
* Default value: `21.0`
* Range/values: `15.0` to `30.0`, `0.5` step

Controls the minimum ideal temperature of the room, below which a negative penalty begins to apply to the room health. Must be less than the Room Health Max Temperature.

#### Room Health Max Temperature

* Entity schema: `number.supersensor_XXXXXX_room_health_max_temperature`
* Default value: `25.0`
* Range/values: `15.0` to `30.0`, `0.5` step

Controls the maximum ideal temperature of the room, above which a negative penalty begins to apply to the room health. Must be greater than the Room Health Min Temperature.

#### Room Health Temperature Penalty

* Entity schema: `number.supersensor_XXXXXX_room_health_temperature_penalty`
* Default value: `10`
* Range/values: `1` to `10`, `1` step

Controls the amount that each °C of deviance from the Min/Max temperature values contributes to the overall temperature subscore, e.g. a value of `10` will deduct 10% from the 100% Temperature subscore for each 1°C of deviance.

#### Room Health Temperature Weight

* Entity schema: `number.supersensor_XXXXXX_room_health_temperature_weight`
* Default value: `0.3`
* Range/values: `0.00` to `1.00`, `0.01` step

Controls the contribution of the temperature subscore towards the overall health score, as a decimal representation of percentage. The total sum of the Temperature Weight, Humidity Weight, and VOC Weight cannot exceed `1.00`.

#### Room Health Min Humidity

* Entity schema: `number.supersensor_XXXXXX_room_health_min_humidity`
* Default value: `40`
* Range/values: `20` to `80`, `1` step

Controls the minimum ideal humidity (%) of the room, below which a negative penalty begins to apply to the room health. Must be less than the Room Health Max Humidity.

#### Room Health Max Humidity

* Entity schema: `number.supersensor_XXXXXX_room_health_max_humidity`
* Default value: `60`
* Range/values: `20` to `80`, `1` step

Controls the maximum ideal humidity (%) of the room, above which a negative penalty begins to apply to the room health. Must be greater than the Room Health Min Humidity.

#### Room Health Humidity Penalty

* Entity schema: `number.supersensor_XXXXXX_room_health_humidity_penalty`
* Default value: `5`
* Range/values: `1` to `10`, `1` step

Controls the amount that each % of deviance from the Min/Max humidity values contributes to the overall humidity subscore, e.g. value of `5` will deduct 5% from the 100% Humidity subscore for each 1% of deviance.

#### Room Health Humidity Weight

* Entity schema: `number.supersensor_XXXXXX_room_health_humidity_weight`
* Default value: `0.3`
* Range/values: `0.00` to `1.00`, `0.01` step

Controls the contribution of the humidity subscore towards the overall health score, as a decimal representation of percentage. The total sum of the Humidity Weight, Humidity Weight, and VOC Weight cannot exceed `1.00`.

#### Room Health VOC Weight

* Entity schema: `number.supersensor_XXXXXX_room_health_voc_weight`
* Default value: `0.4`
* Range/values: `0.00` to `1.00`, `0.01` step

Controls the contribution of the VOC subscore towards the overall health score, as a decimal representation of percentage. The total sum of the Humidity Weight, Humidity Weight, and VOC Weight cannot exceed `1.00`.

**Note:** Unlike Temperature and Humdity, the threshold and penalty values for VOC levels are fixed, rather than configurable. They are set on a discontinuous curve based on typical VOC concentration level thresholds. Full details can be found [in the ESPHome configuration](/supersensor.yaml#L891).

### Voice Assistant & Response

#### Wake Word Selector

* Entity schema: `select.supersensor_XXXXXX_wake_word_selector`
* Default value: `Computer`
* Range/values: `Computer`, `Hey Jarvis`, `Hey Mycroft`, `Okay Nabu`, `Alexa`, `Hey Friday`, `Hey Wabi`, `Wasabi`

Controls the wake word to use for the voice pipeline.

See also: [Enable Voice Support](#enable-voice-support)

#### Wake Word Sensitivity

* Entity schema: `select.supersensor_XXXXXX_wake_word_sensitivity`
* Default value: `Default`
* Range/values: `Default`, `More sensitive`, `Very sensitive`

Controls the sensitivity thresholds of the Wake Word. Each model has specific values for the three possible values, set at build time. Use increasing sensitivity values if you find your chosen wake word isn't understood well enough.

See also: [Wake Word Selector](#wake-word-selector)

#### Assistant/Assistant 2

* Entity schema: `select.supersensor_XXXXXX_assistant`/`select.supersensor_XXXXXX_assistant_2`
* Default value: confguration-dependent
* Range/values: configuration-dependent

**Note:** This entity is created/set by Home Assistant Assist Pipelines, not ESPHome. Its entity schema may include any adjustments to the Friendly Name value.

Set the Home Assistant Assist Pipeline(s) that the Voice Assistant will be assigned to. You may have up to 2 with Home Assistant 2025.11 and newer.

#### Finished speaking detection

* Entity schema: `select.supersensor_XXXXXX_finished_speaking_detection`
* Default value: `Default`
* Range/values: `Default`, `Relaxed`, `Aggressive`

Controls the threshold for detecting the end of speech in the Voice Assistant. In our testing, we've found no appreciable difference between the various options but your experience may differ.

#### LED Brightness %: Listening

* Entity schema: `number.supersensor_XXXXXX_led_brightness_listening`
* Default value: `100`
* Range/values: `0` to `100`, `1` step

Controls the brightness level percentage of the LEDs when in the Voice Assistant "listening" state (blue). Set lower to decrease the brightness level if desired.

#### LED Brightness %: Processing

* Entity: schema: `number.supersensor_XXXXXX_led_brightness_processing`
* Default value: `75`
* Range/values: `0` to `100`, `1` step

Controls the brightness level percentage of the LEDs when in the Voice Assistant "processing" state (cyan). Set lower to decrease the brightness level if desired.

#### LED Brightness %: Responding

* Entity schema: `number.supersensor_XXXXXX_led_brightness_responding`
* Default value: `100`
* Range/values: `0` to `100`, `1` step

Controls the brightness level percentage of the LEDs when in the Voice Assistant "responding" state (green or red). Set lower to decrease the brightness level if desired

#### LED Brightness %: Presence

* Entity schema: `number.supersensor_XXXXXX_led_brightness_presence`
* Default value: `25`
* Range/values: `0` to `100`, `1` step

Controls the brightness level percentage of the LEDs when the Voice Assistant is idle and presence is detected ("white").

See also: [Enable Presence LED](#enable-presence-led).

### LD2410C Radar

The SuperSensor exposes almost all available options from the [LD2410 ESPHome module](https://esphome.io/components/sensor/ld2410/), with the exception of the "Out pin"; while this pin is connected, we do not use it, prefering the UART interface for data acquisition.

The LD2410C operates on the basis of "gates", specific slices of distance from the front of the sensor. Each gate has a threshold value for "move" (quick movements/pulses) and "still" (longer, slower movements) as well as an energy value for those two types. Depending on which gates have values above their thresholds, the sensor calculates an overall distance measurement of any moving objects as well as a total overall set of energy levels, and thus an overall presence indicator. The sensor features 8 gates, plus an additional 0th gate that never reports movement, though this can be adjusted lower if desired.

#### LD2410C Bluetooth

* Entity schema: `switch.supersensor_XXXXXX_ld2410c_bluetooth`
* Default value: `On`
* Range/values: `On`/`Off`

Controls whether the LD2410C BLE interface is active (for use with the HLKRadarTool app).

#### LD2410C Engineering Mode

* Entity schema: `switch.supersensor_XXXXXX_ld2410c_engineering_mode`
* Default value: `Off`
* Range/values: `On`/`Off`

Controls whether the LD2410C is in "Engineering Mode", which will display energy values for individual gates and permit calibration.

#### LD2410C Calibration

* Entity schema: `button.supersensor_XXXXXX_ld2410c_calibration`

When pressed, will begin a self-calibration routine lasting ~030 seconds:
  * 10s: Initial setup
  * 900s: Noise detection
  * 20s: Final setup and query

Once completed, the various gate values below will be automatically set based on the detected noise levels during the calibration.

**Note:** The room must be empty before beginning a calibration or results will be skewed!

See also: [HLK-LD2410C Radar Sensor Calibration](#hlk-ld2410C-radar-sensor)

#### LD2410C Query Params

* Entity schema: `button.supersensor_XXXXXX_ld2410c_query_params`

When pressed, will fetch the latest configuration values from the LD2410C, without waiting for the normal update interval (~60s).

#### LD2410C Restart

* Entity schema: `button.supersensor_XXXXXX_ld2410c_restart`

When pressed, will trigger an internal soft restart of the LD2410C MCU module.

#### LD2410C Factory Reset

* Entity schema: `button.supersensor_XXXXXX_ld2410c_factory_reset`

When pressed, will trigger a complete reset of all stored configuration values in the LD2410C MCU module, resetting it to factory defaults.

#### LD2410C Timeout

* Entity schema: `number.supersensor_XXXXXX_ld2410c_timeout`
* Default value: `5.0`
* Range/values: `0.0` to `65535.0`

Controls how long, in seconds, the LD2410C will report presence after the radar energy values drop below the thresholds. Values of 30 to 90 are typical, though higher or lower values may be useful if some cases. If any gate cross back above the threshold before this timeout is reached, the presence status will be reset again.

#### LD2410C Distance Resolution

* Entity schema: `select.supersensor_XXXXXX_ld2410c_distance_resolution`
* Default value: `0.75`
* Range/values: `0.75`, `0.2`

Controls the distance, in metres, that each gate represents, and therefore what the maximum range of the radar sensor is (6.0m or 1.6m). Generally `0.75` is the correct value for a SuperSensor, though this can be set to `0.2` for specific usecases.

#### LD2410C Max Move Distance Gate

* Entity schema: `number.supersensor_XXXXXX_ld2410c_max_move_distance_gate`
* Default value: `8`
* Range/values: `2` to `8`

Controls the furthest gate which is used by the HLK-LD2410C for moving targets. If set to a value less than 8, the gates above this number are ignored, shortening the detection distance accordingly.

#### LD2410C Max Still Distance Gate

* Entity schema: `number.supersensor_XXXXXX_ld2410c_max_still_distance_gate`
* Default value: `8`
* Range/values: `2` to `8`

Controls the furthest gate which is used by the HLK-LD2410C for stationary targets. If set to a value less than 8, the gates above this number are ignored, shortening the detection distance accordingly.

#### LD2410C GX Move Threshold (G0-G8)

* Entity schema: `number.supersensor_XXXXXX_ld2410c_gX_move_threshold` (`gX` = `g0` through `g8`)
* Default value: Set By Calibration
* Range/values: `0` to `100`

Controls the threshold level of the specified gate for moving targets; the energy level detected must be higher than this threshold for movement to be detected at the gate. A value of 100 functionally disables the gate.

#### LD2410C GX Still Threshold (G0-G8)

* Entity schema: `number.supersensor_XXXXXX_ld2410c_gX_still_threshold` (`gX` = `g0` through `g8`)
* Default value: Set By Calibration
* Range/values: `0` to `100`

Controls the threshold level of the specified gate for stationary targets; the energy level detected must be higher than this threshold for movement to be detected at the gate. A value of 100 functionally disables the gate.

## Sensors

The SuperSensor exposes over 3 dozen sensors for use. This section provides an exhaustive list of the available sensors, organized into broad categories based on logical groupings, rather than how they are displayed in the device UX in Home Assistant.

### Overall/Device Sensors

#### SuperSensor Occupancy

* Entity schema: `binary_sensor.supersensor_XXXXXX_supersensor_occupancy`
* Unit: `Clear`/`Detected`
* Class: Occupancy
* Update: Instant

An overall occupancy sensor, derived from the child occupancy sensors configured with the "Occupancy Detect Mode" and "Occupancy Clear Mode" configuration entries.

> A unified "occupancy" presence detection system, with configurable inbound and outbound detection options selecting from the radar, PIR, and light level sensors in various possible combinations. This provides a user with a great variety of options for controlling presence detection and clearing, as well as a single unified sensor for use in automations. On inbound, the occupancy is triggered by a logical "and" of the configured sensors (all must fire), while outbound is triggered by a logical "or" (any one clearing clears the occupancy); this allows for the configuration of very "safe" detection in both directions if needed, or simple fallback to a single mechanism in either direction.

See also: [Occupancy Detect Mode](#occupancy-detect-mode), [Occupancy Clear Mode](#occupancy-clear-mode)

#### Assist Satelite

* Entity schema: `assist_satelite.supersensor_XXXXXX_assist_satelite`
* Unit: `Idle`/`Listening`/`Processing`/`Responding`
* Class: Assist
* Update: Instant

The current status of the Home Assistant Assist satellite, mapping to the LED states.

**Note:** This entity is created by Home Assistant itself, not ESPHome.

#### ESP32 Free Memory

* Entity schema: `sensor.supersensor_XXXXXX_esp32_free_memory`
* Unit: Bytes (SI)
* Class: Number
* Update: 15s

The current free memory of the ESP32. Useful for debug purposes.

#### ESP32 Heap Free

* Entity schema: `sensor.supersensor_XXXXXX_esp32_heap_free`
* Unit: Bytes (SI)
* Class: Number
* Update: 15s

The current free heap memory of the ESP32. Useful for debug purposes.

#### ESP32 Heap Max Block

* Entity schema: `sensor.supersensor_XXXXXX_esp32_heap_max_block`
* Unit: Bytes (SI)
* Class: Number
* Update: 15s

The maximum contiguous block of free heap memory of the ESP32. Useful for debug purposes.

#### ESP32 PSRAM Free

* Entity schema: `sensor.supersensor_XXXXXX_esp32_psram_free`
* Unit: Bytes (SI)
* Class: Number
* Update: 15s

The current free amount of PSRAM memory of the ESP32. Useful for debug purposes.

#### ESP32 CPU Frequency

* Entity schema: `sensor.supersensor_XXXXXX_esp32_cpu_frequency`
* Unit: Hz
* Class: Number
* Update: 15s

The current CPU frequency of the ESP32. Useful for debug purposes.

#### ESP32 Loop Time

* Entity schema: `sensor.supersensor_XXXXXX_esp32_loop_time`
* Unit: Milliseconds
* Class: Number
* Update: 15s

The current time that the ESP32/ESPHome main loop takes to run. Useful for debug purposes.

#### ESP32 Temperature

* Entity schema: `sensor.supersensor_XXXXXX_esp32_temperature`
* Unit: °C
* Class: Temperature
* Update: 15s

The current MCU temperature of the ESP32 module.

#### ESP32 Uptime

* Entity schema: `sensor.supersensor_XXXXXX_esp32_uptime`
* Unit: Seconds
* Class: Number
* Update: 5s

The current uptime of the ESP32 device, since last restart/power-on.

#### Reset Reason

* Entity schema: `sensor.supersensor_XXXXXX_reset_reason`
* Unit: N/A
* Class: Text
* Update: On Connect

The last given device restart reason if available.

#### ESPHome Version

* Entity schema: `sensor.supersensor_XXXXXX_esphome_version`
* Unit: N/A
* Class: Text
* Update: On Connect

The current ESPHome software version running on the ESP32.

#### WiFi MAC Address

* Entity schema: `sensor.supersensor_XXXXXX_wifi_mac_address`
* Unit: N/A
* Class: Text
* Update: On Connect

The MAC address of the WiFi module of the ESP32. The last 6 hexidecimal characters (ignoring colons `:`) consitutes the SuperSensor ID.

#### WiFi IP Address

* Entity schema: `sensor.supersensor_XXXXXX_wifi_ip_address`
* Unit: N/A
* Class: Text
* Update: On Connect

The IP address of the WiFi module of the ESP32.

#### WiFi RSSI

* Entity schema: `sensor.supersensor_XXXXXX_wifi_rssi`
* Unit: dBm
* Class: Number
* Update: 30s

The current WiFi RSSI (signal level) of the ESP32.

#### WiFi SSID

* Entity schema: `sensor.supersensor_XXXXXX_wifi_ssid`
* Unit: N/A
* Class: Text
* Update: On Connect

The currently-connected WiFi network name.

#### WiFi BSSID

* Entity schema: `sensor.supersensor_XXXXXX_wifi_bssid`
* Unit: N/A
* Class: Text
* Update: On Connect

The currently-connected WiFi BSSID (station/AP MAC address).

#### Device Info

* Entity schema: `sensor.supersensor_XXXXXX_device_info`
* Unit: N/A
* Class: Text
* Update: On Connect

Detailed device information about the ESP32 MCU. Useful for debug purposes.

### Environmental Sensors

#### Room Health

* Entity schema: `sensor.supersensor_XXXXXX_room_health`
* Unit: `Excellent`/`Great`/`Good`/`Fair`/`Poor`/`Bad`
* Class: Text
* Update: 15s

The current textual representation of the Room Health Score, for human-readability.

| Score  | Text |
|---|---|
| =100%  | Excellent |
| >=95%  | Great |
| >=90%  | Good |
| >=80%  | Fair |
| >=60%  | Poor |
| <60% | Bad |

See also: [Room Health](#room-health)

#### Room Health Score

* Entity schema: `sensor.supersensor_XXXXXX_room_health_score`
* Unit: `%`
* Class: Number
* Update: 15s

The current percentage representation of the Room Health.

See also: [Room Health](#room-health)

#### SGP41 VOC Index

* Entity schema: `sensor.supersensor_XXXXXX_sgp41_voc_index`
* Unit: N/A
* Class: Number
* Update: 15s

The raw index value for VOC reported by the SGP41 sensor. This is a unitless positive integer which must be interpreted to generate other values. The internal algorithm of the SGP41 attempts to keep this around 100.

#### SGP41 TVOC (ppb)

* Entity schema: `sensor.supersensor_XXXXXX_sgp41_tvoc_ppb`
* Unit: `ppb`
* Class: Number
* Update: 15s

The calculated parts-per-billion (ppb) of Total VOCs as calculated from the SGP41 VOC Index. The calculation here is based on the published calculations for the AirGradient ONE.

#### SGP41 TVOC (µg/m³)

* Entity schema: `sensor.supersensor_XXXXXX_sgp41_tvoc_mg_m3`
* Unit: `µg/m³`
* Class: Number
* Update: 15s

The calculated micrograms per cubic metre (µg/m³) of Total VOCs as calculated from the SGP41 VOC I?ndex. The calculation here is based on the published calculations for the AirGradient ONE.

#### SGP41 eCO2 (appr.)

* Entity schema: `sensor.supersensor_XXXXXX_sgp41_eco2_appr`
* Unit: `ppm`
* Class: Number
* Update: 15s

The approximate calculated parts-per-million (ppm) of estimated CO2 as calculated from the SGP41 VOC Index. The calculation here is based on the published calculations for the AirGradient ONE.

#### SGP41 NOx Index

* Entity schema: `sensor.supersensor_XXXXXX_sgp41_nox_index`
* Unit: N/A
* Class: Number
* Update: 15s

The raw index value for NOx reported by the SGP41 sensor. This is a unitless positive integer which must be interpreted to generate other values; currently we do not as there are no published formulae for this. The internal algorithm of the SGP41 attempts to keep this around 1.

#### SHT45 Temperature

* Entity schema: `sensor.supersensor_XXXXXX_sht45_temperature`
* Unit: `°C`
* Class: Number
* Update: 15s

The current temperature (°C) reported by the SHT45 sensor, after adjustment from the Temperature Offset value.

**Note:** We only support °C; future versions may add selectable support for °F or K as well.

See also: [Temperature Offset](#temperature-offset)

#### SHT45 Relative Humidity

* Entity schema: `sensor.supersensor_XXXXXX_sht45_relative_humidity`
* Unit: `%`
* Class: Number
* Update: 15s

The current relative humidity (%) reported by the SHT45 sensor, after adjustment from the Temperature Offset value (via Magnus formula) to correct for said offset, and the Humidity Offset value.

See also: [Humidity Offset](#humidity-offset)

#### SHT45 Absolute Humidity

* Entity schema: `sensor.supersensor_XXXXXX_sht45_absolute_humidity`
* Unit: `g/m³`
* Class: Number
* Update: 15s

The current absolute humidity in grams per cubic metre, calculated from the SHT45 Temperature and SHT45 Relative Humidity values.

#### SHT45 Dew Point

* Entity schema: `sensor.supersensor_XXXXXX_sht45_dew_point`
* Unit: `°C`
* Class: Number
* Update: 15s

The current dew point (°C), calculated from the SHT45 Temperature and SHT45 Relative Humidity values.

### Light Sensors

#### Light Presence

* Entity schema: `binary_sensor.supersensor_XXXXXX_light_presence`
* Unit: `Clear`/`Detected`
* Class: Occupancy
* Update: ~2s

The light occupancy sensor based on the TSL2591 measurement and "Light Presence Threshold" configuration entry.

See also: [Light Presence Threshold](#light-presence-threshold)

#### TSL2591 Illumination

* Entity schema: `sensor.supersensor_XXXXXX_tsl2591_illumination`
* Unit: `lx`
* Class: Number
* Update: 2s

The current full-spectrum (combined visible + infrared) illumination value reported by the TSL2591 sensor.

#### TSL2591 Gain

* Entity schema: `sensor.supersensor_XXXXXX_tsl2591_gain`
* Unit: N/A
* Class: Number
* Update: 2s

The current gain value applied to the raw signal by the TSL2591 sensor.

#### TSL2591 Raw Full Spectrum

* Entity schema: `sensor.supersensor_XXXXXX_tsl2591_raw_full_spectrum`
* Unit: N/A
* Class: Number
* Update: 2s

The current raw full-spectrum (combined visible + infrared) value reported by the TSL2591 sensor.

#### TSL2591 Raw Infrared

* Entity schema: `sensor.supersensor_XXXXXX_tsl2591_raw_infrared`
* Unit: N/A
* Class: Number
* Update: 2s

The current raw infrared value reported by the TSL2591 sensor.

#### TSL2591 Raw Visible

* Entity schema: `sensor.supersensor_XXXXXX_tsl2591_raw_visible`
* Unit: N/A
* Class: Number
* Update: 2s

The current raw visible value reported by the TSL2591 sensor.

### Radar Sensors

#### LD2410C Presence

* Entity schema: `binary_sensor.supersensor_XXXXXX_ld2410c_presence`
* Unit: `Clear`/`Occupied`
* Class: Occupancy
* Update: Instant

The LD2410C occupancy sensor directly from the LD2410C module.

#### LD2410C Presence Distance

* Entity schema: `sensor.supersensor_XXXXXX_ld2410c_presence_distance`
* Unit: `cm`
* Class: Number
* Update: Instant

The calculated distance to a detected object/person (either moving or stationary) by the LD2410C module.

#### LD2410C Moving Target

* Entity schema: `sensor.supersensor_XXXXXX_ld2410c_moving_target`
* Unit: `Clear`/`Detected`
* Class: Occupancy
* Update: Instant

The LD2410C occupancy sensor for a moving target(s) directly from the LD2410C module.

#### LD2410C Moving Distance

* Entity schema: `sensor.supersensor_XXXXXX_ld2410c_moving_distance`
* Unit: `cm`
* Class: Number
* Update: Instant

The calculated distance to a detected moving object/person by the LD2410C module.

#### LD2410C Moving Energy

* Entity schema: `sensor.supersensor_XXXXXX_ld2410c_moving_energy`
* Unit: `%`
* Class: Number
* Update: Instant

The detected energy level of a detected moving object/person by the LD2410C module.

#### LD2410C Still Target

* Entity schema: `sensor.supersensor_XXXXXX_ld2410c_still_target`
* Unit: `Clear`/`Detected`
* Class: Occupancy
* Update: Instant

The LD2410C occupancy sensor for a stationary target(s) directly from the LD2410C module.

#### LD2410C Still Distance

* Entity schema: `sensor.supersensor_XXXXXX_ld2410c_still_distance`
* Unit: `cm`
* Class: Number
* Update: Instant

The calculated distance to a detected stationary object/person by the LD2410C module.

#### LD2410C Still Energy

* Entity schema: `sensor.supersensor_XXXXXX_ld2410c_still_energy`
* Unit: `%`
* Class: Number
* Update: Instant

The detected energy level of a detected stationary object/person by the LD2410C module.

#### LD2410C Calibration Status

* Entity schema: `sensor.supersensor_XXXXXX_ld2410c_calibration_status`
* Unit: N/A
* Class: Text
* Update: Instant

The current status of the LD2410C Calibration routine.

See also: [LD2410C Calibration](#ld2410c-calibration)

#### LD2410C Firmware Version

* Entity schema: `sensor.supersensor_XXXXXX_ld2410c_firmware_version`
* Unit: N/A
* Class: Text
* Update: Instant

The current firmware version of the LD2410C MCU.

#### LD2410C MAC Address

* Entity schema: `sensor.supersensor_XXXXXX_ld2410c_mac_address`
* Unit: N/A
* Class: Text
* Update: Instant

The Bluetooth Low-Energy (BLE) MAC address of the LD2410C MCU.

#### LD2410C GX Move Energy (G0-G8)

* Entity schema: `number.supersensor_XXXXXX_ld2410c_gX_move_energy` (`gX` = `g0` through `g8`)
* Unit: `%`
* Class: Number
* Update: Instant

The detected energy level of a detected moving object/person by the LD2410C module at the specified gate.

**Note:** These sensors only report valid values when the LD2410C Engineering Mode switch is active.

See also: [LD2410C Engineering Mode](#ld2410c-engineering-mode), [LD2410C Move Energy](#ld2410c-move-energy)

#### LD2410C GX Still Energy (G0-G8)

* Entity schema: `number.supersensor_XXXXXX_ld2410c_gX_still_energy` (`gX` = `g0` through `g8`)
* Unit: `%`
* Class: Number
* Update: Instant

The detected energy level of a detected stationary object/person by the LD2410C module at the specified gate.

**Note:** These sensors only report valid values when the LD2410C Engineering Mode switch is active.

See also: [LD2410C Engineering Mode](#ld2410c-engineering-mode), [LD2410C Still Energy](#ld2410c-still-energy)

### PIR Sensors

#### PIR Presence

* Entity schema: `binary_sensor.supersensor_XXXXXX_pir_presence`
* Unit: `Clear`/`Detected`
* Class: Occupancy
* Update: Instant

The PIR occupancy sensor based on the PIR GPIO output and "PIR Hold Time" configuration entry.

See also: [PIR Hold Time](#pir-hold-time)

#### PIR GPIO

* Entity schema: `binary_sensor.supersensor_XXXXXX_pir_gpio`
* Unit: `Clear`/`Occupied`
* Class: Occupancy
* Update: Instant

The raw GPIO output of the SR602 PIR sensor.

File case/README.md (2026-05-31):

# SuperSensor v3.x Case

This is a 3D-printable case/enclosure for the SuperSensor v3.0 module. This case is recommended for proper sensor operation, and for aesthetics and mounting purposes, but is not strictly required.

The design features several individual parts:

* A body with standoffs to hold the assembled PCB with openings for ventilation and the USB connections on the right side (facing the sensor).
* A cover with holes for the microphone (conical focusing), the PIR (w/lens), and the LED insert, along with a back cover for the descender.
* An LED insert diffuser with a hole for the UESM.
* A wall-mount assembly featuring two 45+° securable ball joints and 3 mounting options.
* A table-mount assembly featuring one 45+° securable ball joint and a flat bottom including cutouts for 4 ~13mm rubber anti-slip feet.

You can [tinker the design on TinkerCAD here](https://www.tinkercad.com/things/gx66mJQMgR6).

The case design and images in this folder are © 2025 [Joshua M. Boniface](https://www.boniface.me) and licensed under the [Creative Commons Attribution-ShareAlike (BY-SA) 4.0](LICENSE) license. The design contains elements from [Nikolay "darkfrei"'s Universal Ball Joint design](https://www.thingiverse.com/thing:6804839) for the mounting components, provided under the same license.

* [Printing](#printing)
   * [Main Case Models](#main-case-models)
   * [Mounting Models](#mounting-models)
* [Assembly & Installation](#assembly--installation)
   * [Case Assembly](#case-assembly)
   * [Mount Assembly (Common)](#mount-assembly-common)
   * [Mount Assembly & Installation (Table)](#mount-assembly--installation-table)
   * [Mount Assembly & Installation (Wall)](#mount-assembly--installation-wall)

## Printing

In this directory are 8 `.obj`-format CAD files collectively providing the case and mounting system. They should be compatible as-is with any slicing software and 3D printer model; no rotation or other transformations are required.

As a general set of parameters, all models should be printed with the following, **except** for any differences specified in specific models below. All values are provided as their OrcaSlicer 2.3 names; your slicer may differ.

* 0.16mm layer height, or a clean multiple
* No brim or raft
* Tree supports
* Supports touching buildplate only
* 0.8mm Support/object first layer gap
* 7-10 wall loops
* 7-10 shell layers (top + bottom)
* 25% infill
* Concentric patterns for infill
* Concentric patterns for surfaces (visual only)
* Back (preferred) or Aligned seams (visual only)

All other options are specific to your printer, material, and desired effect and can be adjusted as needed.

The parts should be printed in a solid, durable material of any colour you wish, except for the insert as noted below. We use white or black ABS (depending on the aesthetics of the final location) for our official prints.

### Main Case Models

These are the primary models that make up the case. Each case requires 1x `case-body`, 1x `case-cover`, and 1x `case-insert`.

#### `case-body`

This is the main body of the case which houses the assembled sensor PCB. It includes a large side opening for the insertion of a USB-C cable of "normal" size into either ESP32-S3 input, which should fit most cables.

#### `case-cover`

This is the front face of the case. It clips into the body with 4 triangular grip clips (2 each on the top and bottom). It features 3 openings for components:

  * A 7.6mm conical opening for the microphone.
  * An 10.4 mm diameter circular opening for the SR602 PIR and lens.
  * A 57.2 x 9.2 mm rectangular opening, with a center 14.4 mm circular protrusion, for the LED cover below.

It also features a "decender" feature that covers the protrusion of the UESM for the SHT45 temperature sensor, with a square opening for the SHT45 itself, as well as a small press-fit cover for the back of this feature.

#### `case-insert`

This insert fits into the large rectangle in the cover, and provides a diffuser for the feedback/status LEDs, an opening for the UESM's circular component, and cutouts for the UESM's protrusion.

This part is inserted into the face separately during assembly, though a multi-material printer could concievably print it directly into the face during printing (with modifications to adjust the height accordingly).

This part should be printed in a solid, durable material of **a natural, transluscent, or transparent** colour (it must let white light through reasonably well). We use transparent ABS in for our official prints.

### Mounting Models

These models provide mounting options for the case in various configurations depending on your environment. These models are completely optional should you wish to devise your own mounting scheme, but two common configurations are provided:

* A wall/ceiling mount with ~100° of adjustment freedom across two ball joints; each mount requires 2x `mount-ball`, 2x `mount-nut`, 1x `mount-tube`, and 1x of **either** `mount-base-adhesive`, `mount-base-screw`, or `mount-base-ties.
* A table/desk mount with ~50° of adjustment freedom across a single ball joint; each mount requires 1x `mount-ball`, 1x `mount-nut`, and 1x `mount-base-table`.

#### `mount-ball`

This is a ball and rod for a ball joint with a flanged (conical) bottom, for attaching to the `case-body` back and, for wall mounts, the `mount-ball-base` below.

This part requires **10 wall loops** for optimal strength and **random seams** to avoid excessive binding in any one position.

#### `mount-nut`

This is a nut for the `mount-ball` to connect it to either the `mount-extension-tube` or the `mount-table-base` below. It goes between the ball and either the `case-body` or `mount-ball-base` with the thread openingfacing out (towards the ball); final assembly to another part locks it into place permanently.

#### `mount-base-table`

This is a flat-based riser with a sleek profile and a single screw-end at the top to attach a ball joint to. The model features rounded corners and a swoop up into the riser for style reasons, as well as 4 bottom indents to attach ~13 mm diameter rubber feet for traction.

This part _may_ require a **brim** depending on material properties; for our ABS prints a 110°C build plate temperature counteracts this, but your material may differ.

#### `mount-base-adhesive`

This is a base for the `mount-ball` part when used as part of a wall mount, to affix it to the wall via an adhesive layer like a 3M Command™ strip. It features an indent sized to accept the conical base of the `mount-ball` part.

#### `mount-base-screws`

This is a base for the `mount-ball` part when used as part of a wall mount, to affix it to the wall via a pair of M4 or #6 wood screws. It features an indent sized to accept the conical base of the `mount-ball` part, and two countersunk holes that should fit the aforementioned screw heads.

#### `mount-base-ties`

This is a base for the `mount-ball` part when used as part of a wall mount, to affix it to an object with a pair of ~6mm cable ties. It features an indent sized to accept the conical base of the `mount-ball` part, and two countersunk rectangular holes that should fit the aforementioned cable ties.

#### `mount-tube`

This is a double screw-ended tube which connects the two ball joints in the wall/ceiling mount; it is not required for the table/desk mount.

This part requires a **brim** or it has a habit of popping off the build plate mid-print.

There are two variations of this part: `-10mm` has a 10mm grip, while `-15mm` has a 15mm grip. We personally use 10mm as the default, but if you want the extra range of angle afforded by the extra length you may use the 15mm version.

## Assembly & Installation

To begin, print the parts above as required for the specific mounting type you want.

For proper assembly & installation, you will also need:

* Cyanoacrylate superglue, to join several components depending on your configuration; a precision applicator is ideal.

* For the adhesive wall mount, one 3M Command™ strip (Medium size, or similar double-sided wall-safe adhesive) is required, to affix the second ball joint mount to a wall, ceiling, or other location while permitting non-destructive removal.

* For the screw wall mount, two M4/#6 wood screws with tapered heads are required.

* For the table mount, circular rubber feet (~13mm or less in diameter) are recommended to avoid slipping, but are not required; there are indents for optimal placement.

### Case Assembly

1. Construct a SuperSensor board with all components.

2. Insert the `case-insert` into the opening of the `case-cover`, applying steady, even pressure face-down against a surface to fully seat it. Due to overextrusion, the fit may sometimes be tight, and trimming may be required for optimal fit. Cyanoacrylate superglue can also help ensure stability if the insert will not fit snugly.

3. Take the `case-body` and insert the SuperSensor board such that it aligns with the 4 standoffs and the USB connectors with the opening at the bottom of the case. The board should press cleanly down onto them.

4. Remove the cap (both pieces, exposing the raw PIR element) from the SR602 PIR sensor.

5. Take the `case-cover` and place it over the UESM board and PIR sensor, aligning it with protruding sensors and the `case-body`.

6. Insert the `case-cover` latches into one side of the `case-body`, and then gently flex it to press down the latches on the other side; it should snap nicely into place securing the cover to the body. Readjust the sensor modules such that they are fully inside the holes.

7. Align and gently press the cap back onto the SR602 PIR sensor until it is seated well, avoiding pressing down on the non-pin side; seating on an angle may help. Once aligned press down firmly to fully seat it.

### Mount Assembly (Common)

1. Take the `mount-nut` and place one of/the `mount-ball` into it with the screw opening facing the ball (the same orientation they are printed); the nut should become captive on the ball while being able to screw into the other components.

2. Apply a small dab of superglue onto the bottom of the `mount-ball` conical rod.

3. Take the completed case assembly, and turn it around to the back. Press the glued surface of the `mount-ball` into the hatched "recess" in the `case-body`, gently turn it at least 1/4 turn, then allow the glue to cure.

### Mount Assembly & Installation (Table)

**Warning:** Never overtighten the ball nut! You want it tight enough so that it won't drift, but not so tight as to crack the plastic.

1. Apply rubber feet to the mounting inserts on the bottom of the `mount-base-table` if desired.

2. Take your `mount-base-table` and your `mount-nut` + `mount-ball` + case, and screw the nut onto the screw portion of the riser. The ball should become captive, but do not fully tighten it yet.

3. Place the completed unit in the desired location, and adjust the sensor to point where you would like, slowly tightening the nut as you adjust.

4. Once you are happy with the direction, tighten the nut a little more while firmly holding the unit so it does not twist; you may need to "preload" the position slightly to work with the nut pulling the ball with it.

5. Perform any final fine manual adjustments gently, then apply a little more pressure onto the nut to lock it fully into place.

### Mount Assembly & Installation (Wall)

**Warning:** Never overtighten the ball nuts! You want it tight enough so that it won't drift, but not so tight as to crack the plastic.

1. Take the `mount-nut` and place the remaining `mount-ball` into it with the screw opening facing the ball; the nut should become captive on the ball while being able to screw into the other components.

2. Apply a small dab of superglue onto the bottom of the `mount-ball` conical rod.

3. Take the `mount-base-adhesive`, `mount-base-screws`, or `mount-base-ties` (whichever you printed) and press the glued surface of the `mount-ball` into the recess in the base, rotating it in place several times to ensure optimal glue coverage and that the ball is level with the base, then allow the glue to cure.

4. Take your `mount-tube` and your `mount-nut` + `mount-ball` + case, and screw the nut onto one end of the `mount-tube`. The ball should become captive, but do not fully tighten it yet.

5. Take your combined `mount-tube` + case assembly, and screw the nut from the second `mount-ball` onto it, creating a single line with the case at one end, the `mount-tube` in the center, and the base at the other end. Do not fully tighten either nut yet.

6. Affix a 3M Command™ strip (Medium, or substitute) to the back of the base if applicable.

7. Prepare the surface wall/ceiling/etc. to accept the 3M Command™ strip (or substitute), then adhere the base to the surface, if applicable.

8. Adjust the sensor to point in roughly the direction you wish it to, and secure one nut; this will be your "gross" adjustment.

9. Adjust the sensor further to the exact position while gradually tightening the other nut to lock it into position, firmly holding the unit so it does not twist; you may need to "preload" the position slightly to work with the nut pulling the ball with it.

5. Perform any final fine manual adjustments gently, then apply a little more pressure onto the nuts to lock them fully into place.

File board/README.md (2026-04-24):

# SuperSensor v3.x Board Designs

This is a collection of [EasyEDA](https://easyeda.com/) schematics and board desgins for the SuperSensor v3.x's components.

The design features several individual parts:

* A core SuperSensor board which ties the various components together.
* The UESM comprising three discrete boards.

You can import the design definition files (`*.easyeda.json`) directly into EasyEDA via "File" -> "Open" -> "EasyEDA". The schematic is provided for reference in both EasyEDA and SVG formats; if you just wish to manufacture the boards, you only need to import the board definitions, then via "Fabrication" -> "One-click Order PCB/SMT" complete the order at [JLCPCB](https://jlcpcb.com). We order all boards in a black silkscreen with lead-free HASL (for use with low-temperature Ga-Sn solder paste) and all other options as default.

You can also see the designs directly on [OSHWLab here](https://oshwlab.com/joshuaboniface/supersensor-3-0).

The board design and images in this folder are © 2025 [Joshua M. Boniface](https://www.boniface.me) and licensed under the [Creative Commons Attribution-ShareAlike (BY-SA) 4.0](LICENSE) license.

* [Schematic](#schematic)
* [Boards](#boards)
* [Assembly](#assembly)

## Schematic

The schematic is visible here in SVG format, and also as an EasyEDA definition in [schematic.easyeda.json](schematic.easyeda.json).

Design schematic

The individual parts can be found, with their labels (`R1`, etc.) in the [main README parts list](https://github.com/joshuaboniface/supersensor/tree/v3.x?tab=readme-ov-file#pcb-design--diy).

## Boards

There are 4 boards; 1 for the main SuperSensor and 3 for the Unified Environment Sensor Module (UESM).

### SuperSensor

SuperSensor v3.x board - front

SuperSensor v3.x board - back

This is the main board of the SuperSensor, which connects the ESP32-S3, modules, LEDs, and passive components and provides a structural mount to the case via four corner mounting holes.

### UESM Top

UESM Top - front

UESM Top - back

This is the top board of the Unified Environment Sensor Module (UESM) which contains the main sensors (SHT45, SGP41, and TSL2591) on its top surface; it connects to the following boards via surface pads on the bottom.

The board features a long component to house the SHT45 sensor, protruding it approximately 20cm downward out of the main case body, in order to properly isolate the sensor from internal heating.

### UESM Spacer

UESM Spacer - front

UESM Spacer - back

This is the middle board of the UESM, which serves only as a pass-through spacer to extend the height of the top board by a further 1.6mm, allowing that board to cleanly protrude past the connector pin tops and out of the case top.

### UESM Base

UESM Base - front

UESM Base - back

This is the main board of the UESM, which connects to the main PCB with a standard 3.3V-only I²C 4-pin header. It features all the passive components for driving the 3 sensor modules on the bottom, while the top is occupied by the connections to the upper boards.

## Assembly

### UESM

**Warning**: Assembly of the UESM is not for the faint of heart. It requires a steady hand and very gentle application of heat. Follow these directions exactly for success. We also offer [UESM modules for sale]() if this feels too daunting but you wish to DIY the rest of the project.

To assembly the UESM you will need, in addition to the listed components in the main README, the following:

* Isopropyl alcohol (99% ideal) and paper towel.
* Low-temperature (138°C SnGa) solder paste (for delicate SMD components).
* Normal (PbSn) solder (for the final pin headers, if you wish).
* A hot air reflow station, and optionally a hotplate, with precise temperature control.
* A soldering iron with a (semi-)fine tip.
* A set of helping hands (aligator clips on adjustable extensions).
* Two pairs of fine precise tweezers.
* A temperature-safe soldering work area.

There are two processes possible - a more manual process using only hot air, and a process using both a hotplate and hot air. The latter is far less error prone and more forgiving, but requires a suitable hotplate. The steps for both are fundamentally the same, the only difference being the use of the hotplate to perform the component soldering on the `top` and `bottom` boards; we leave it up to the reader to reinterpret the hot-air only instructions below in this regard. Both processes require hot air for joining the two pieces.

Before proceeding, clean all PCBs thoroughly with isopropyl alcohol and paper towel.

The assembly proceeds in three steps: first the assembly of the `top` board's top surface components (sensors), then the assembly of the `bottom` board's bottom surface components (passives), then finally the joining of both boards with the spacer.

##### `top` PCB

1. Take a `top` PCB and place it into the helping hands by its edge, with the component side facing up and the pad side facing down.

2. Carefully apply a very small amount of solder paste to each top surface pad. If you think it's not enough, it's just right. We found a stencil more cumbersome than it was worth and just use a hyper-fine sringe tip on the solder paste along with careful concentration. Place each component onto its pads with tweezers.

3. Heat the hot air station to 240C; no higher. Apply heat to the **bottom** of the `top` PCB until all the solder reflows. Check carefully for any bridges or failed joins and gently reflow in the same way as necessary. **Never apply heat directly to the sensors themselves!**

4. Wait for the board to cool.

##### `base` PCB

1. Take a `base` PCB and place it flat on your work surface, component-side (bottom) up.

2. Apply a fair amount of solder paste to each component pad, ensuring enough coverage for the components to firmly sit into the paste. Place each component onto its pads with tweezers.

3. Heat the hot air station to 240-260C. Apply heat directly to each component until all the solder reflows. Check carefully for any bridges or failed joins and gently reflow as necessary.

4. Wait for the board to cool.

5. Insert the 4-pin header into place, and flip the PCB around.

6. Using a standard soldering iron and solder, solder the pins into place. Note that due to the `top` PCB design, you **must** solder on these pins now, before joining the `top` and `base` PCBs.

##### Joining

**Note:** This step can be very finicky. Patience, a steady hand, and a careful eye is required.

1. Inset the `base` PCB by its pins into the helping hands so that it is securely held and sitting flat with its top surface up (components down), and so that the board is "face up" to you (pins furthest away).

2. Place a liberal amount of solder paste onto each of the bridge holes, starting with a spiral slightly outside of the edge of the castellation, and working inwards.

3. Take a `spacer` PCB, and place it on top of the `base` PCB, carefully aligning each hole and ensuring straightness.

4. Heat the hot air station to 240-260C. Apply heat to the top of the `spacer` PCB while gently pressing down with tweezers, until the two PCBs join flat and make a good solder connection on each pin. Verify electrical connectivity to be certain.

5. Repeat the process in step 2 with the `spacer` PCB.

6. Take the completed `top` PCB, and place it on top of the `spacer` PCB, carefully aligning each hole and ensuring straightness. There will likely be a gap on the side closes to you as the arm rests on the pin protrusions; this is normal.

7. Heat the hot air station to 240-260C. Apply heat to the **bottom** of the `base` PCB. It will take a little time for all the boards to heat and the solder paste to begin to melt.

8. When the paste begins to melt, start pressing down lightly on the top of the `top` PCB with tweezers, to ensure the boards join. It should be clear once they do as the `top` PCB will now "want" to sit flush with the `spacer` PCB and not fall.

9. Remove the heat, and acting quickly, ensure correct alignment of the circular PCB components with each other and with the printed ring on the `base` PCB, and of the extension of the `top` PCB; it should be exactly parallel to the short edges of the `base` PCB. Use the tweezers to **gently** nudge it from the sides at its far end to align it; the solder and flux may fight you slightly, but this helps ensure good alignment.

10. Let the entire assembly cool fully and inspect it visually for any deficiencies, specifically for any component misalignment on the bottom of the `base` PCB due to heat application in steps 7-9.

11. Perform final electrical tests, ensuring that the `3V3`, `GND`, `SDA`, and `SCL` signals fully reach from the pins to the contact points on the SHT45 sensor.

The UESM is now fully assembled and ready for final testing and insertion into a SuperSensor.

##### Troubleshooting

If you find there are inter-board connectivity issues, the most likely cause is insufficient solder paste bridging the PCB boads. To solve this you can do the following:

1. Re-apply heat as in step 7 of the `Joining` process until the joins between the boards weakens.

2. Remove the `top` PCB, leaving the `spacer` and `base` boards together, and apply additional solder paste to the pads on the bottom of the `top` PCB.

3. Repeat steps 6-9 of the `Joining` process until the boards are re-joined and aligned. Retest electrical connectivity and repeat if necessary.

4. Clean up any extra solder that has flowed out of the `base` PCB's holes with careful application of heat.

### SuperSensor

To assembly the SuperSensor you will need, in addition to the listed components in the main README, the following:

* Isopropyl alcohol (99% ideal) and paper towel.
* Normal (PbSn) solder or low-temperature (138°C SnGa) solder paste (if lead-free is desired).
* A soldering iron with a (semi-)fine tip.
* A set of helping hands (aligator clips on adjustable extensions).
* A temperature-safe soldering work area.

Assembly of this module is fairly straightforward and aside from 3 SMD components is all through-hole. The SMD components are relatively large and can be soldered using normal solder and a soldering iron one edge at a time, though if you have low-temperature solder paste from the UESM assembly you may use that along with hot air to reflow them instead.

1. Clean the PCB thoroughly with isopropyl alcohol and paper towel.

2. Solder on the 3 SMD passive components (C4, R5, & R6); if using solder paste, leverage hot air or a hotplate, or carefully use a solder iron with a fine tip.

3. Insert the LEDs into their holes, carefully noting the direction and aligning the flat side with the silkscreen. Solder in the leads carefully using a fine tip to avoid bridges, and trim off the excess leads.

4. Place the 3-, 4-, and 5-pin female connectors from the front of the PCB, then solder them in from the back of the PCB. Use another board or flat surface as a stabilizer as needed. Always solder one pin first, check alignment, then solder the remaining pins.

5. Place the 22-pin female connectors from the back of the PCB, then solder them in from the front of the PCB. Use the ESP32 module as a positioning guide as required; we tend to solder both the pins to the ESP, and the connectors to the board, at the same time, starting with the four corners for stability and then proceeding down the rows.

6. Bridge the "In-Out" jumper on the front of ESP32-S3 module with solder, located on the front of the ESP32-S3 PCB near pins 11 and 12, to enable 5V output on the 5Vin pin.

7. Insert the remaining components into their respective connectors.

8. Connect the board via USB to your computer using the USB-C connector labeled "COM" (the bottom of the two when the sensor is upright). Using the ESPHome software, flash the `supersensor.yaml` configuration onto the ESP32. **Note:** Sometimes, you may need to reset the board into bootloader mode by holding the "Boot" button and simultaneously pressing the "Rst" button, in order to apply the configuration. Once finished, press the "Rst" button again to boot into normal mode.

9. Verify functionality via the console log (using `esphome logs supersensor.yaml` if disconnected in the previous step), ensuring that all components are detected and begin reporting data.

10. Adopt the completed SuperSensor onto your WiFi network and add it to Home Assistant.

11. Place the SuperSensor into the [case](../case) and mount it in your desired location. Use the USB-C connector labeled "USB" (the top of the two when the sensor is upright) for power in normal usage.

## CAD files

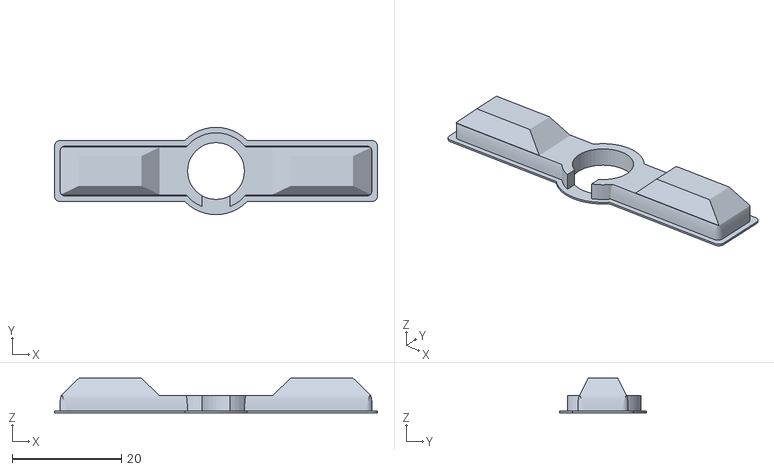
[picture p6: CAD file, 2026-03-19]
case/case-insert.obj
59.2 x 16.0 x 6.40

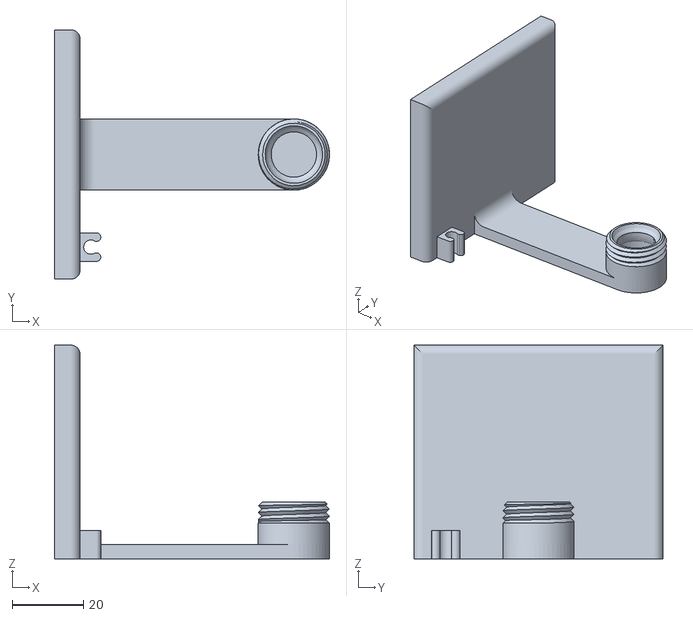
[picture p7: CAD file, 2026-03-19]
case/mount-base-table.obj
77.2 x 70.0 x 60.0

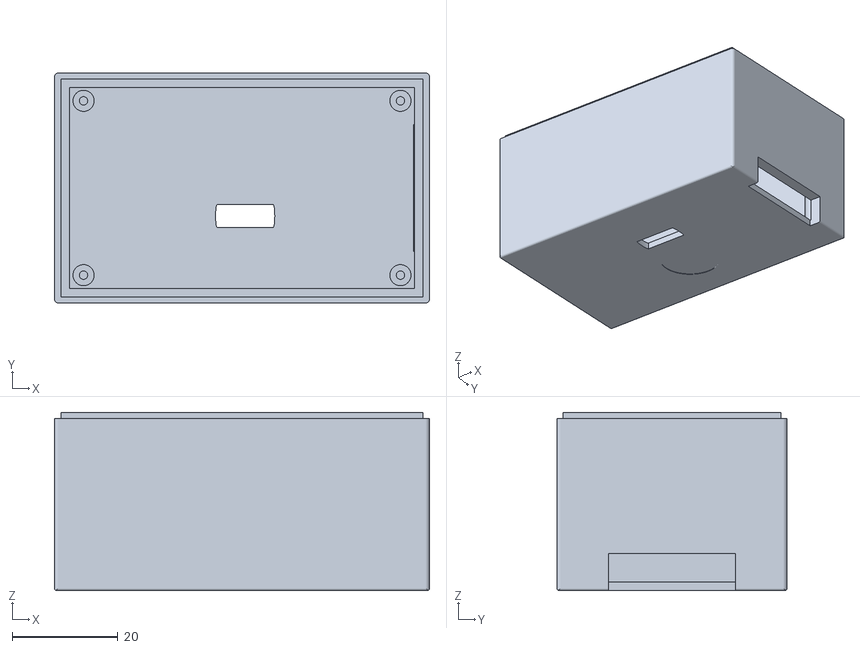
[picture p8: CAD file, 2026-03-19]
case/case-body.obj
71.0 x 43.6 x 33.8

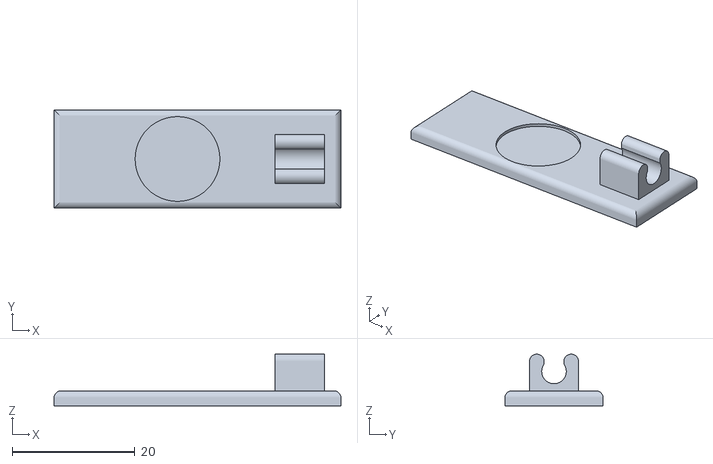
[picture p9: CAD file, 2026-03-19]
case/mount-base-adhesive.obj
46.7 x 16.0 x 8.40

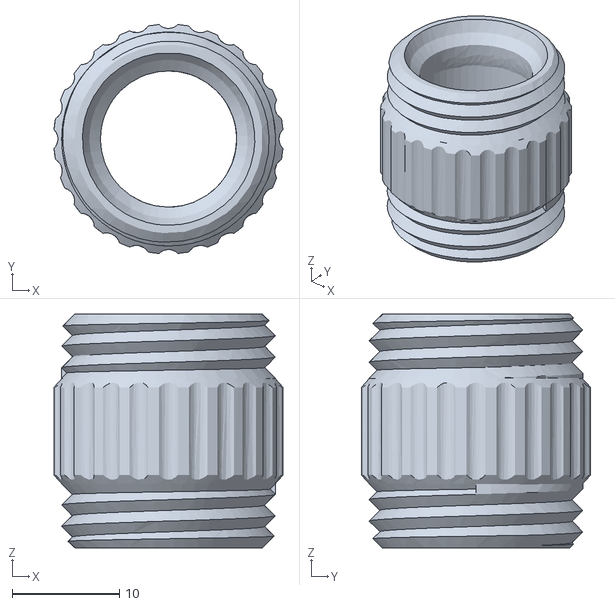
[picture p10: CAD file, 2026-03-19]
case/mount-tube-10mm.obj
21.4 x 21.4 x 21.8

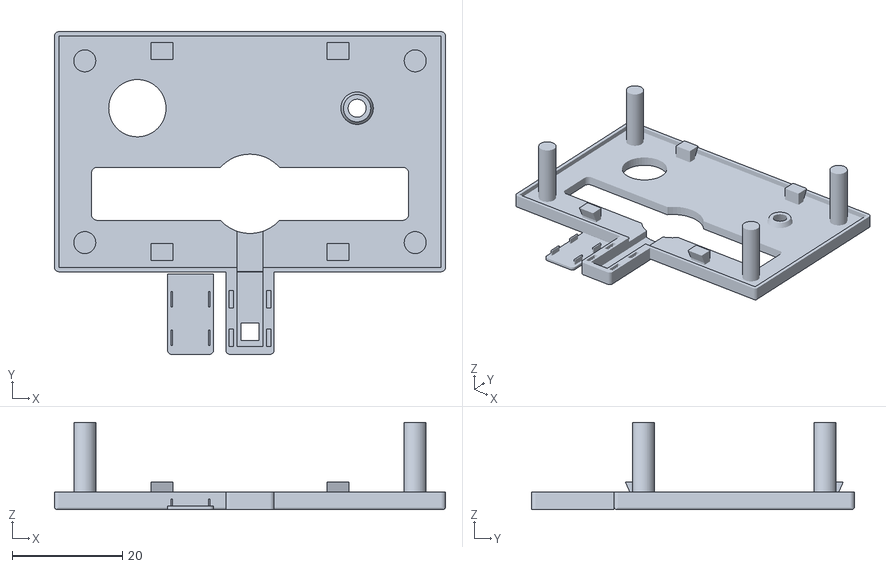
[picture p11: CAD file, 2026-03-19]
case/case-cover.obj
71.0 x 58.6 x 15.8

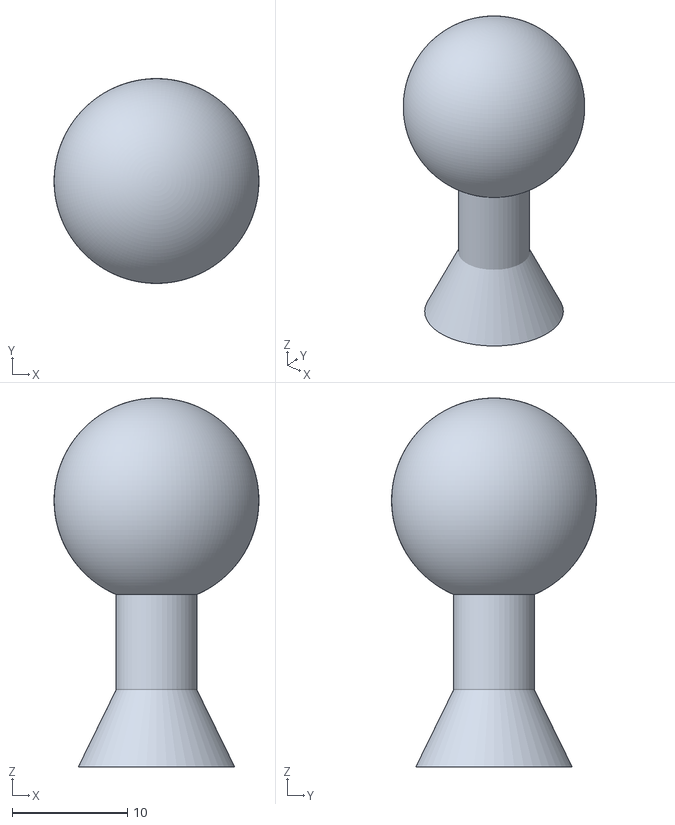
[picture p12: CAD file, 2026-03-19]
case/mount-ball.obj
17.8 x 17.8 x 32.1

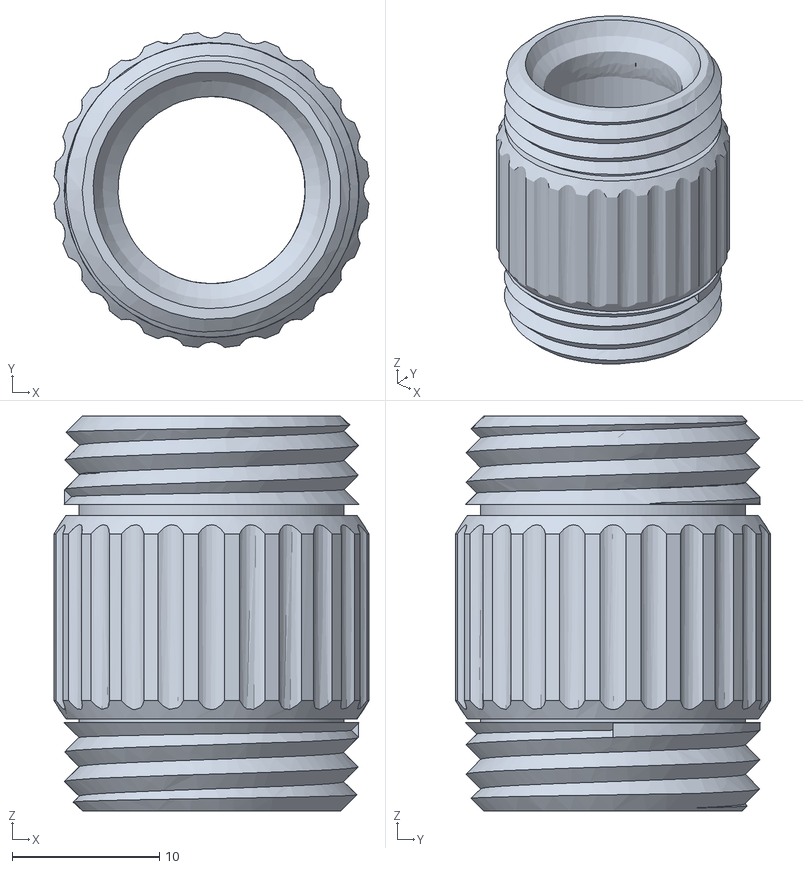
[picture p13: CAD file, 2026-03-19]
case/mount-tube-15mm.obj
21.4 x 21.4 x 26.8

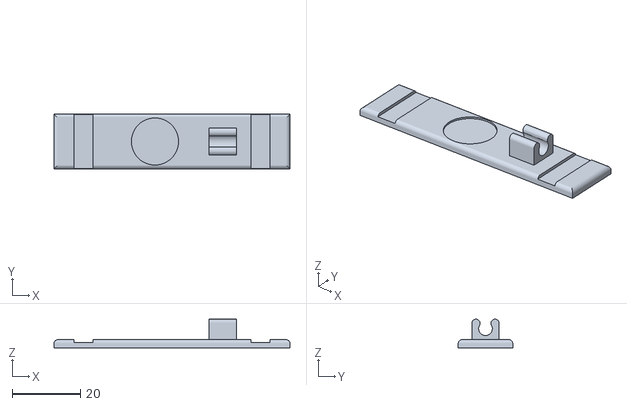
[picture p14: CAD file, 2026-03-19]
case/mount-base-ties.obj
69.2 x 16.0 x 8.40

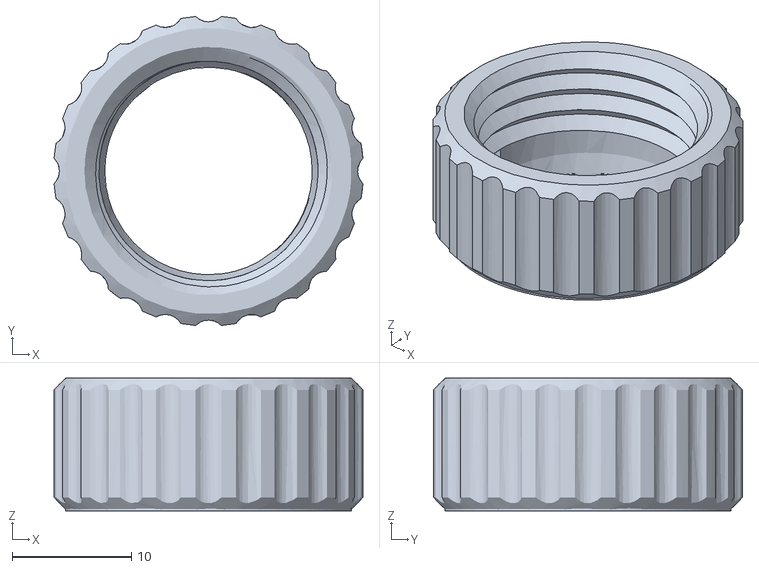
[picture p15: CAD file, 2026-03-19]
case/mount-nut.obj
25.9 x 25.9 x 11.1

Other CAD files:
case/mount-base-screws.obj

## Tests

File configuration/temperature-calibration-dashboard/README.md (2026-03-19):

# SuperSensor v3.x Temperature Calibration Dashboard

This page provides and documents a temperature calibration dashboard for use in Home Assistant, in order to calibrate your SuperSensor v3.x devices using a [MicroEnv 2.x sensor](https://github.com/joshuaboniface/microenv).

The MicroEnv provides a reliable, consistent temperature reference to help calibrate the SuperSensor's temperature offset, due to the negative effects of internal heating from the other components. Unlike many discrete temperature probes, the MicroEnv is also based on ESPHome and can be easily integrated into Home Assistant, providing a convenient way to visualize the data for analysis.

## Prerequisites

1. You will need both a MicroEnv 2.x sensor, as well as the SuperSensor, installed in your desired location.

2. The MicroEnv should be placed such that its temperature probe is within about 10cm of the SuperSensor's UESM face, in a roughly similar horizontal and vertical alignment, as in the following picture. Avoid placing the MicroEnv **above** the SuperSensor as this can result in a temperature drift, as can directly attaching the MicroEnv to the SuperSensor case; keep them separate.

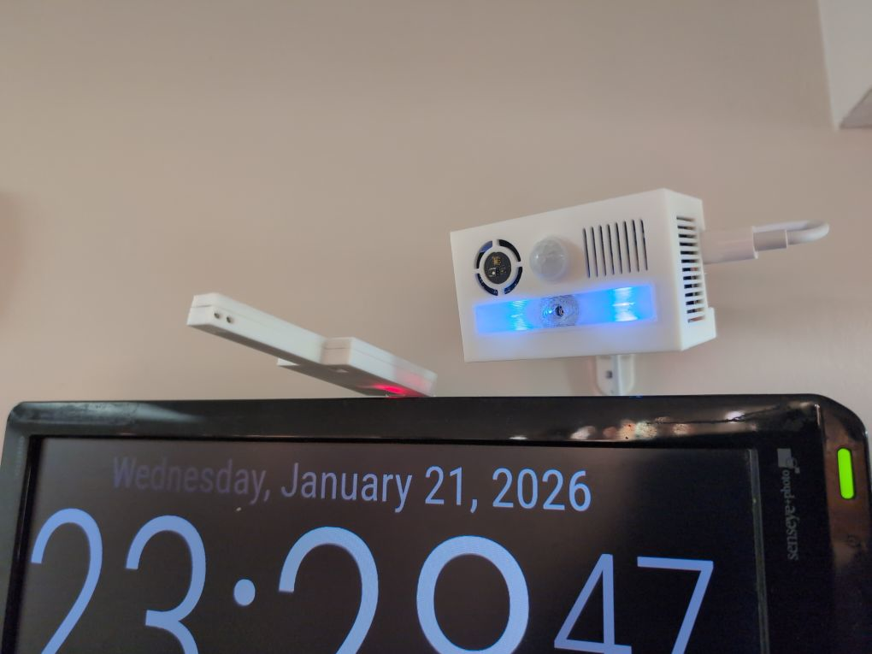
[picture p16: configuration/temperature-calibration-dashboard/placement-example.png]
Placement Example
   

3. Both devices should be imported into Home Assistant using their default friendly names (to create generic entity IDs); they may be renamed later.

## Helper Entities

You will want to create 3 template helper entities in order to provide sensors for the temperature, relative humidity, and absolute humidity deltas for later graphing. We use very generic names to faciliate easy configuration of multiple SuperSensors, but you can name these whatever you like and simply modify the entity references in the dashboard later.

### "SuperSensor Calibration Temperature Delta"

Create the entity by going to "Settings" -> "Devices & services" -> "Helpers" and clicking "Create helper". Select "Template", and then "Sensor". Enter the following values for the entity.

In the `State` template, replace `XXXXXX` with the 6-digit ID of your SuperSensor to calibrate, and `YYYYYY` with the 6-digit ID of your reference MicroEnv Sensor.

* Name: `SuperSensor Calibration Temperature Delta`
* State: `{{ (states('sensor.supersensor_XXXXXX_sht45_temperature')|float - states('sensor.microenv_sensor_YYYYYY_sht45_temperature')|float)|round(1) }}`
* Unit of measurement: `°C`
* Device class: `Temperature delta` (or `Temperature`)
* State class: `Measurement`

Save the resulting template sensor configuration.

If you need to later modify this template (e.g. to switch out which SuperSensor you are calibrating), select the Helper entity, click the ⚙️  icon, click "Template options", then edit the "State" contents.

### "SuperSensor Calibration Relative Humidity Delta"

Create the entity by going to "Settings" -> "Devices & services" -> "Helpers" and clicking "Create helper". Select "Template", and then "Sensor". Enter the following values for the entity.

In the `State` template, replace `XXXXXX` with the 6-digit ID of your SuperSensor to calibrate, and `YYYYYY` with the 6-digit ID of your reference MicroEnv Sensor.

* Name: `SuperSensor Calibration Relative Humidity Delta`
* State: `{{ (states('sensor.supersensor_XXXXXX_sht45_relative_humidity')|float - states('sensor.microenv_sensor_YYYYYY_sht45_relative_humidity')|float)|round(1) }}`
* Unit of measurement: `%`
* Device class: `Relative Humidity`
* State class: `Measurement`

Save the resulting template sensor configuration.

If you need to later modify this template (e.g. to switch out which SuperSensor you are calibrating), select the Helper entity, click the ⚙️  icon, click "Template options", then edit the "State" contents.

### "SuperSensor Calibration Absolute Humidity Delta"

Create the entity by going to "Settings" -> "Devices & services" -> "Helpers" and clicking "Create helper". Select "Template", and then "Sensor". Enter the following values for the entity.

In the `State` template, replace `XXXXXX` with the 6-digit ID of your SuperSensor to calibrate, and `YYYYYY` with the 6-digit ID of your reference MicroEnv Sensor.

* Name: `SuperSensor Calibration Absolute Humidity Delta`
* State: `{{ (states('sensor.supersensor_XXXXXX_sht45_absolute_humidity')|float - states('sensor.microenv_sensor_YYYYYY_sht45_absolute_humidity')|float)|round(2) }}`
* Unit of measurement: `g⁄m³`
* Device class: `Absolute Humidity`
* State class: `Measurement`

Save the resulting template sensor configuration. You may need to re-edit the Helper entity by selecting it, clicking on the ⚙️  icon, and setting the "Display precision" to `0.00` to properly show the required decimal places, if it does not properly default to this.

If you need to later modify this template (e.g. to switch out which SuperSensor you are calibrating), select the Helper entity, click the ⚙️  icon, click "Template options", then edit the "State" contents.

## Dashboard

Create a new dashboard, edit it, then open the "Raw configuration editor" and paste the following dashboard YAML. This dashboard requires the [`apexcharts-card` HACS addon](https://github.com/RomRider/apexcharts-card).

For every instance of them, replace `XXXXXX` with the 6-digit ID of your SuperSensor to calibrate, and `YYYYYY` with the 6-digit ID of your reference MicroEnv Sensor.

```
views:
  - type: sections
    max_columns: 4
    title: SuperSensor Calibration
    path: supersensor-calibration
    icon: mdi:test-tube
    sections:
      - type: grid
        cards:
          - type: heading
            icon: mdi:thermometer
            heading: Temperature
            heading_style: title
            grid_options:
              rows: auto
          - type: entities
            entities:
              - entity: sensor.supersensor_XXXXXX_sht45_temperature
                name: SuperSensor
              - entity: sensor.microenv_sensor_YYYYYY_sht45_temperature
                name: Reference
              - entity: sensor.supersensor_calibration_temperature_delta
                name: ΔT
          - type: custom:apexcharts-card
            graph_span: 48h
            header:
              show: false
              title: Sensors
              show_states: false
              colorize_states: true
            series:
              - entity: sensor.supersensor_XXXXXX_sht45_temperature
                name: SuperSensor
                stroke_width: 2
              - entity: sensor.microenv_sensor_YYYYYY_sht45_temperature
                name: Reference
                stroke_width: 2
            apex_config:
              chart:
                height: 250px
              xaxis:
                tooltip:
                  enabled: false
              tooltip:
                shared: true
                intersect: false
                fixed:
                  enabled: true
                  position: topLeft
            all_series_config:
              group_by:
                duration: 1min
                func: avg
                fill: last
          - type: custom:apexcharts-card
            graph_span: 48h
            header:
              show: false
              title: Delta
              show_states: false
              colorize_states: true
            series:
              - entity: sensor.supersensor_calibration_temperature_delta
                name: ΔT
                stroke_width: 2
            apex_config:
              chart:
                height: 250px
              legend:
                show: true
                showForSingleSeries: true
              xaxis:
                tooltip:
                  enabled: false
              tooltip:
                shared: true
                intersect: false
                fixed:
                  enabled: true
                  position: topLeft
            all_series_config:
              group_by:
                duration: 1min
                func: avg
                fill: last
          - type: entities
            entities:
              - entity: number.supersensor_XXXXXX_temperature_offset
                name: Offset
      - type: grid
        cards:
          - type: heading
            heading_style: title
            heading: Relative Humidity
            icon: mdi:water-percent
            grid_options:
              rows: auto
          - type: entities
            entities:
              - entity: sensor.supersensor_XXXXXX_sht45_relative_humidity
                name: SuperSensor
              - entity: sensor.microenv_sensor_YYYYYY_sht45_relative_humidity
                name: Reference
              - entity: sensor.supersensor_calibration_relative_humidity_delta
                name: ΔRH
          - type: custom:apexcharts-card
            graph_span: 48h
            header:
              show: false
              title: Sensors
              show_states: false
              colorize_states: true
            series:
              - entity: sensor.supersensor_XXXXXX_sht45_relative_humidity
                name: SuperSensor
                stroke_width: 2
              - entity: sensor.microenv_sensor_YYYYYY_sht45_relative_humidity
                name: Reference
                stroke_width: 2
            apex_config:
              chart:
                height: 250px
              xaxis:
                tooltip:
                  enabled: false
              tooltip:
                shared: true
                intersect: false
                fixed:
                  enabled: true
                  position: topLeft
            all_series_config:
              group_by:
                duration: 1min
                func: avg
                fill: last
          - type: custom:apexcharts-card
            graph_span: 48h
            header:
              show: false
              title: Delta
              show_states: false
              colorize_states: true
            series:
              - entity: sensor.supersensor_calibration_relative_humidity_delta
                name: ΔRH
                stroke_width: 2
            apex_config:
              chart:
                height: 250px
              legend:
                show: true
                showForSingleSeries: true
              xaxis:
                tooltip:
                  enabled: false
              tooltip:
                shared: true
                intersect: false
                fixed:
                  enabled: true
                  position: topLeft
            all_series_config:
              group_by:
                duration: 1min
                func: avg
                fill: last
          - type: entities
            entities:
              - entity: number.supersensor_XXXXXX_humidity_offset
                name: Offset
      - type: grid
        cards:
          - type: heading
            heading: Absolute Humidity
            heading_style: title
            icon: mdi:water-percent-alert
            grid_options:
              rows: auto
          - type: entities
            entities:
              - entity: sensor.supersensor_XXXXXX_sht45_absolute_humidity
                name: SuperSensor
              - entity: sensor.microenv_sensor_YYYYYY_sht45_absolute_humidity
                name: Reference
              - entity: sensor.supersensor_calibration_absolute_humidity_delta
                name: ΔAH
          - type: custom:apexcharts-card
            graph_span: 48h
            header:
              show: false
              title: Sensors
              show_states: false
              colorize_states: true
            series:
              - entity: sensor.supersensor_XXXXXX_sht45_absolute_humidity
                name: SuperSensor
                stroke_width: 2
              - entity: sensor.microenv_sensor_YYYYYY_sht45_absolute_humidity
                name: Reference
                stroke_width: 2
            apex_config:
              chart:
                height: 250px
              xaxis:
                tooltip:
                  enabled: false
              tooltip:
                shared: true
                intersect: false
                fixed:
                  enabled: true
                  position: topLeft
            all_series_config:
              group_by:
                duration: 1min
                func: avg
                fill: last
          - type: custom:apexcharts-card
            graph_span: 48h
            header:
              show: false
              title: Delta
              show_states: false
              colorize_states: true
            series:
              - entity: sensor.supersensor_calibration_absolute_humidity_delta
                name: ΔAH
                stroke_width: 2
            apex_config:
              chart:
                height: 250px
              legend:
                show: true
                showForSingleSeries: true
              xaxis:
                tooltip:
                  enabled: false
              tooltip:
                shared: true
                intersect: false
                fixed:
                  enabled: true
                  position: topLeft
            all_series_config:
              group_by:
                duration: 1min
                func: avg
                fill: last
```

Like the helper template sensors above, if you wish to calibrate additional SuperSensors later, simply edit the dashboard and swap out the SuperSensor IDs.

## Using The Dashboard

The new dashboard will show you both the current values, delta, and graphs of the SHT45 values, as well as the two exposed offset values from the SuperSensor.

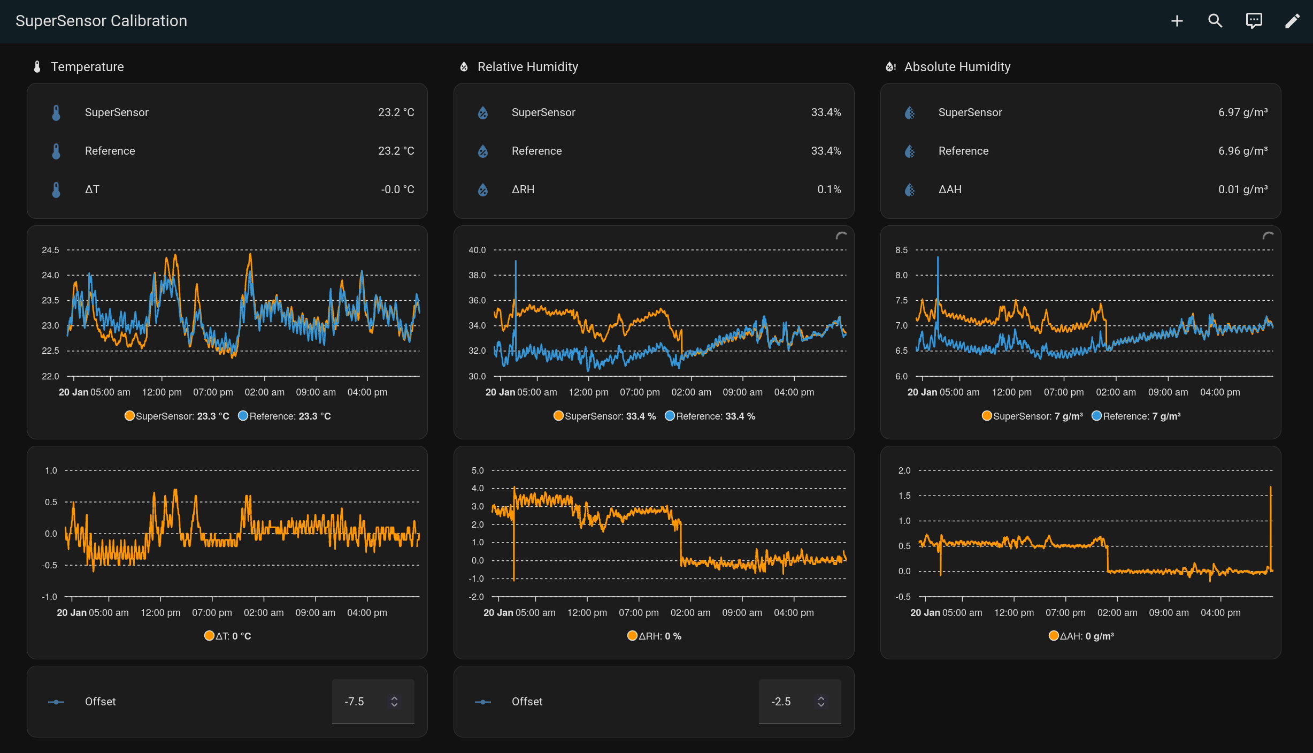
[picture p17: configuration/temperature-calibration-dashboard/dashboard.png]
Dashboard in Home Assistant


To use it, let both sensors collect data for at least 24 hours, and then observe the graphs. You will want to adjust the "Offset" value for both Temperature and Relative Humidity such that the `ΔT` and `ΔRH` lines in the second graph of their respective columns is as centered on zero as possible.

In the above example, the Temperture offset has been properly calibrated to `-7.5` for over 48 hours; notice that the `ΔT` graph is mostly centered around `0.0` with only occasional fluctuations, and that the two entity graphs are closely aligned with each other. This is the ideal scenario. The Humidity offset, in contrast, was configured for only 24 hours, and you can see the previous state with a `ΔRH` that was hovering around `2.5`. Thus, we set the Offset to `-2.5` to bring them in line, and the last 24 hours now show a delta mostly centered around `0.0` and the entity graphs closely aligned as expected. Since Absolute Humidity is calculated from the Temperature and Reltive Humidity, once these are calibrated the Absolute Humidity graph should align as well.

Once you have the SuperSensor calibrated, it can be helpful to leave this dashboard running for at least 48 hours, to confirm that the sensor offsets continue to behave as expected and do not require further adjustment.

If the environmental conditions of the SuperSensor change in any way (it is repositioned, etc.), it is advised to re-run this calibration excercise to ensure the offset does not change.

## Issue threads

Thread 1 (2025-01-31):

Micro Wake Word not working anymore

AtrejaAlwinnen, 2025-01-31:
Hi,
until a few weeks ago I was running your sensor with the Micro_wake_word as a test setup.

As that worked well, I have now bought all the hardware and soldered everything together, unfortunately I can't get the Micro_wake_word thing to work anymore.
The hardware is OK, with openwakeword everything works fine.
However, as I run HA on a Pi, it generates about 20% CPU usage.

The first error I get is:

`INFO ESPHome 2024.12.4
INFO Reading configuration /config/esphome/supersensor1-24d9e8.yaml...
INFO Updating https://github.com/esphome/esphome.git@pull/5230/head
WARNING The selected ESP-IDF framework version is not the recommended one. If there are connectivity or build issues please remove the manual version.
WARNING The selected ESP-IDF framework version is not the recommended one. If there are connectivity or build issues please remove the manual version.
Failed config

micro_wake_word: [source /config/esphome/supersensor1-24d9e8.yaml:293]

  'models' is a required option for [micro_wake_word].

  The model parameter has moved to be a list element under the models parameter.
  model: hey_jarvis
  on_wake_word_detected:
    then:
      - voice_assistant.start:
          wake_word: !lambda |-
            return wake_word;`

so i changed your code to:

`micro_wake_word:
  vad:
  models:
    - model: hey_jarvis
  on_wake_word_detected:
    then:
      - voice_assistant.start:
          wake_word: !lambda return wake_word;`

and also enabled:

`voice_assistant:
  microphone: mic
  use_wake_word: true`

Now the code compiles and I can flash the ESP, but the Micro_wake_word function doesn't seem to work.

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

the wake word button is also grayed out.
Do you have any idea what went wrong?

Greetings
Atreja

joshuaboniface, 2025-02-02:
I don't use MWW, so I can't be much help. It's possible this is related to the pinning of the ESP-IDF framework I did a little while ago to get this to work with ESPHome 2024.12.x, but I'm not certain.

AtrejaAlwinnen, 2025-02-02:
Hi, and thanks for the answer.
I was afraid that you wouldn't be able to help me, since the part in the .yaml had already been commented out with the note that it wasn't working properly.
With the Supersensor version 1.1 and before 2024.12, MWW worked for me without any problems.
Is there a way to undo the change?
Other than using the old HomeAssistant version?
Unfortunately, your really great sensor is of no use to me without MWW. :/

joshuaboniface, 2025-02-03:
As you note, I never did get MWW working myself. First thing is to see if you can bump the ESP-IDF versions I set - as long as the rest of the sensor code compiles whatever version is used should be fine. Beyond that pinning to the old version might, unfortunately, be required for now.

joshuaboniface, 2025-02-05:
I'll see if I can spend some time this weekend digging into it and keep you posted here.

AtrejaAlwinnen, 2025-02-05:
That would be really great and would be very happy about it. :)

joshuaboniface, 2025-02-07:
I just pushed some commits to restore things to the Arduino framework (so not ESP-IDF), as well as switch to the BSEC2 library for the IAQ sensor. Feel free to give this version a try with OWW and let me know how it goes.

AtrejaAlwinnen, 2025-02-07:
The code compiles without problems and the sensor runs well under ESPHome 2024.12.4
Open Wake Word also works without problems.
Unfortunately, the Miocro Wake Word still doesn't work.
The section for this no longer corresponds to the current syntax and when I change it to the syntax specified on the ESPHome website, I get the following error message:

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

joshuaboniface, 2025-02-09:
I just realized that myself. Seems you need ESP-IDF to do micro wake word, but need Arduino to do BSEC2.

I'm currently testing how well the BSEC2 library works with the BME680's, so I might go back if it doesn't. Unfortunately though that kinda precludes OWW support for me at this time. If you want to prioritize OWW, you can try switching back to ESP-IDF (i.e. use the tag 1.2 version) but then I think we're back to the beginning again where it just wasn't working.

joshuaboniface, 2025-02-09:
Well the "good" news is BSEC2 is just as utterly useless for IAQ as BSEC1 was, so I guess we can go back to ESP-IDF. I'll push a new version shortly.

joshuaboniface, 2025-02-09:
I've done some testing myself and I can definitely replicate this. Adding some debug logging, on 4.4.8 it simply doesn't work at all with no indication as to why. I also went through and tested various 5.x releases of ESP-IDF and none of them compile successfully. So I think we're stuck until ESPHome puts out a fixed release that properly supports ESP-IDF 5.x.

I would suggest - if one doesn't already exist - opening an issue on the ESPHome GitHub about MWW not working on 4.4.8. Feel free to reference this issue. Perhaps they can provide a pointer.

AtrejaAlwinnen, 2025-02-09:
Thank you very much for your efforts.
I also had no success with the 5.x releases.
I'll take a look at ESPhome and if there is nothing there about MWW I'll open an issue.

joshuaboniface, 2025-05-06:
I finally got some time to look into this, and from my testing so far I'm seeing no problems with MicroWakeWord on ESPHome 2025.5.

```
diff --git a/supersensor.yaml b/supersensor.yaml
index f5bdf48..5be4c3c 100644
--- a/supersensor.yaml
+++ b/supersensor.yaml
@@ -371,16 +371,15 @@ interval:
             App.safe_reboot();
           }

-# Add optional microWakeWord support (on-device wake word)
-# Doesn't work well as of 2024-07-04 so leave disabled
-#micro_wake_word:
-#  model: hey_jarvis
-#  on_wake_word_detected:
-#    then:
-#      - voice_assistant.start:
-#          wake_word: !lambda return wake_word;
-
-# Include the Espressif Audio Development Framework for VAD support
+micro_wake_word:
+  vad:
+  models:
+    - model: hey_jarvis
+  on_wake_word_detected:
+    then:
+      - voice_assistant.start:
+          wake_word: !lambda return wake_word;
+
 esp_adf:
 external_components:
   - source: github://pr#5230
```

Enabled like so, ensured I removed the Wake Word engine from the Assist pipeline, restarted everything, and it "just works".

I'm wondering were you able to get it working with the HomeAssistant-side wake words, with everything working?

joshuaboniface, 2025-05-11:
Sorry I mistook the verison, I am indeed on 2025.4.1.

You might want to adjust the gain, I believe there's an option for that. But in my configuration I'm setting that within the voice_assistant and it seems to "just work" fine.

Also worth noting that the only ESP32 I've ever used for this is the ESP32-WROOM-32D; I haven't tried any others and thus can't really provide assistance with those.

joshuaboniface, 2025-06-16:
I believe I ended up solving this. While I've not backported the fixes to 1.x here (I've moved on to a 2.x design, see the README), the code itself should be easily backported.

In short, I removed the ESP-ADF component, as this is no longer properly supported.

I then ensured I was actually setting the microphone channel to the right one.

And suddenly everything started working perfectly.

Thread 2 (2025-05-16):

Supersensor 2.0 Conversion

joshuaboniface, 2025-05-16:
Over the last several weeks I have been preparing an updated hardware configuration for a Supersensor 2.0.

As part of this, you may have noticed a new repository layout. Things are now split into two branches:

* [v1.x](https://github.com/joshuaboniface/supersensor/tree/v1.x) contains code and models for the original Supersensor design using the Bosch BME680 environmental sensor.
* [v2.x](https://github.com/joshuaboniface/supersensor/tree/v2.x) contains code and models for the updated Supersensor design using the Sensirion SHT45 and SGP30 environmental sensors.

For those with a v1.x Supersensor board or otherwise using the BME680, you should update your ESPHome dashboard configuration for your sensors as follows:

```
packages:
  joshuaboniface.supersensor: github://joshuaboniface/supersensor/supersensor.yaml@1.x
```

For anyone finding this project for the first time (or anyone wanting to upgrade their existing sensors), please review the `v2.x` branch for updated schematics.

The master branch readme has been updated to reflect this change and no files are present in that branch any longer to force a reconfiguration.

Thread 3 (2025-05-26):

Link not working for Supersensor 2.0

OneCreek, 2025-05-26:
https://www.boniface.me/the-supersensor-2.0/ is referenced [current version of the blog post](https://www.boniface.me/the-supersensor-2.0/) but not working in the [Readme](https://github.com/joshuaboniface/supersensor/blob/master/README.md).

Closed 2025-06-16.

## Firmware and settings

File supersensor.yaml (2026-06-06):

---

###############################################################################
# SuperSensor v3.0 ESPHome configuration
###############################################################################
#
#    Copyright (C) 2025 Joshua M. Boniface <joshua@boniface.me>
#
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
###############################################################################

esphome:
  name: supersensor
  name_add_mac_suffix: true
  friendly_name: "Supersensor"
  project:
    name: joshuaboniface.supersensor
    version: "3.0"
  min_version: 2026.3.0
  on_boot:
    - priority: 600
      then:
        - light.turn_on:
            id: output_led
        - delay: 0.25s
        - light.turn_off:
            id: output_led
        - delay: 0.25s
        - light.turn_on:
            id: output_led
        - delay: 0.25s
        - light.turn_off:
            id: output_led
        - lambda: |-
            id(supersensor_occupancy).publish_state(false);
            id(pir_presence).publish_state(false);
            id(light_presence).publish_state(false);
            id(radar_presence).publish_state(false);
            id(ld2410c_calibration_status).publish_state("Idle");
    - priority: -100
      then:
        - if:
            condition:
              - switch.is_on: enable_voice_support
            then:
              - micro_wake_word.start:

preferences:
  flash_write_interval: 15sec

dashboard_import:
  package_import_url: github://joshuaboniface/supersensor/supersensor.yaml@v3.x

esp32:
  variant: esp32s3
  flash_size: 8MB
  cpu_frequency: 240MHz
  framework:
    type: esp-idf

psram:
  # We use an ESP32-S3-N8R2 as reference
  mode: quad
  speed: 80MHz

globals:
  #
  # SHT45 offsets
  #
  - id: temperature_offset
    type: float
    restore_value: true
    initial_value: "-2.0"

  - id: humidity_offset
    type: float
    restore_value: true
    initial_value: "0.0"

  #
  # Room Health settings
  #
  - id: room_health_temperature_min
    type: float
    restore_value: true
    initial_value: "21.0"

  - id: room_health_temperature_max
    type: float
    restore_value: true
    initial_value: "24.0"

  - id: room_health_temperature_penalty
    type: float
    restore_value: true
    initial_value: "10.0"

  - id: room_health_humidity_min
    type: float
    restore_value: true
    initial_value: "40.0"

  - id: room_health_humidity_max
    type: float
    restore_value: true
    initial_value: "60.0"

  - id: room_health_humidity_penalty
    type: float
    restore_value: true
    initial_value: "5.0"

  - id: room_health_voc_weight
    type: float
    restore_value: true
    initial_value: "0.4"

  - id: room_health_temperature_weight
    type: float
    restore_value: true
    initial_value: "0.3"

  - id: room_health_humidity_weight
    type: float
    restore_value: true
    initial_value: "0.3"

  #
  # PIR settings
  #
  - id: pir_hold_time
    type: int
    restore_value: true
    initial_value: "15"

  #
  # Light settings
  #
  - id: light_presence_threshold
    type: int
    restore_value: true
    initial_value: "30"

  #
  # Occupancy settings
  #
  - id: occupancy_detect_mode
    type: int
    restore_value: true
    initial_value: "0"

  - id: occupancy_clear_mode
    type: int
    restore_value: true
    initial_value: "0"

  #
  # API connection tracker
  #
  - id: last_api_connected_time
    type: uint32_t
    restore_value: no
    initial_value: "0"

  #
  # LD2410C ACK tracking (for the calibration sequence)
  #
  - id: ld2410_last_ack_cmd
    type: int
    restore_value: no
    initial_value: "-1"

  - id: ld2410_last_ack_status
    type: int
    restore_value: no
    initial_value: "-1"

  #
  # Wake Word settings
  #
  - id: current_wake_word
    type: std::string
    restore_value: yes
    initial_value: '"mww_computer"'

  #
  # LED Brightness settings
  #
  - id: led_presence_brightness
    type: int
    restore_value: yes
    initial_value: '25'

  - id: led_listening_brightness
    type: int
    restore_value: yes
    initial_value: '100'

  - id: led_processing_brightness
    type: int
    restore_value: yes
    initial_value: '75'

  - id: led_responding_brightness
    type: int
    restore_value: yes
    initial_value: '100'

  #
  # LED State Machine (priority-based)
  #
  - id: led_state
    type: int
    restore_value: no
    initial_value: '0'      # 0=idle, 1=hold, 2=pipeline

  - id: led_substate
    type: int
    restore_value: no
    initial_value: '0'      # 0 idle, 1 listen, 2 stt, 3 success, 4 fail

  - id: led_hold_until
    type: uint32_t
    restore_value: no
    initial_value: '0'
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

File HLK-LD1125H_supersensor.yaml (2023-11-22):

---

###############################################################################
# SuperSensor v1.0 ESPHome configuration
###############################################################################
#
#    Copyright (C) 2023 Joshua M. Boniface <joshua@boniface.me>
#
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
###############################################################################

#
# Compile-time Substitutions
#
substitutions:
  ignored_radar_ranges: |-
    {
      { 2.20, 3.30 },
      { 2.20, 2.75 }
    }

#
# Core configuration
#
esphome:
  name: supersensor
  name_add_mac_suffix: true
  on_boot:
    - priority: 600
      then:
        - light.turn_on:
            id: output_led
            effect: flash
            red: 1
            green: 1
            blue: 1

    - priority: 100
      then:
        # Configure LD1125H via UART
        - uart.write:
            id: LD1125H_UART_BUS
            data: !lambda |-
              std::string mth1_mov_st = "mth1_mov=" + str_sprintf("%.0f",id(LD1125H_mth1_mov).state) + "\r\n";
              return std::vector<uint8_t>(mth1_mov_st.begin(), mth1_mov_st.end());
        - uart.write:
            id: LD1125H_UART_BUS
            data: !lambda |-
              std::string mth2_mov_st = "mth2_mov=" + str_sprintf("%.0f",id(LD1125H_mth2_mov).state) + "\r\n";
              return std::vector<uint8_t>(mth2_mov_st.begin(), mth2_mov_st.end());
        - uart.write:
            id: LD1125H_UART_BUS
            data: !lambda |-
              std::string mth3_mov_st = "mth3_mov=" + str_sprintf("%.0f",id(LD1125H_mth3_mov).state) + "\r\n";
              return std::vector<uint8_t>(mth3_mov_st.begin(), mth3_mov_st.end());
        - uart.write:
            id: LD1125H_UART_BUS
            data: !lambda |-
              std::string mth1_occ_st = "mth1_occ=" + str_sprintf("%.0f",id(LD1125H_mth1_occ).state) + "\r\n";
              return std::vector<uint8_t>(mth1_occ_st.begin(), mth1_occ_st.end());
        - uart.write:
            id: LD1125H_UART_BUS
            data: !lambda |-
              std::string mth2_occ_st = "mth2_occ=" + str_sprintf("%.0f",id(LD1125H_mth2_occ).state) + "\r\n";
              return std::vector<uint8_t>(mth2_occ_st.begin(), mth2_occ_st.end());
        - uart.write:
            id: LD1125H_UART_BUS
            data: !lambda |-
              std::string mth3_occ_st = "mth3_occ=" + str_sprintf("%.0f",id(LD1125H_mth3_occ).state) + "\r\n";
              return std::vector<uint8_t>(mth3_occ_st.begin(), mth3_occ_st.end());
        - uart.write:
            id: LD1125H_UART_BUS
            data: !lambda |-
              std::string rmaxst = "rmax=" + str_sprintf("%.1f",id(LD1125H_rmax).state) + "\r\n";
              return std::vector<uint8_t>(rmaxst.begin(), rmaxst.end());

    - priority: -500
      then:
        - wait_until: api.connected
        - delay: 3s
        - switch.turn_on: use_wake_word
        - delay: 2s
        - switch.turn_off: use_wake_word
        - delay: 2s
        - switch.turn_on: use_wake_word
        - light.turn_off:
            id: output_led

esp32:
  board: esp32dev
  framework:
    type: esp-idf
    sdkconfig_options:
      CONFIG_ESP32_DEFAULT_CPU_FREQ_240: "y"
      CONFIG_ESP32_DEFAULT_CPU_FREQ_MHZ: "240"
      CONFIG_ESP32_DATA_CACHE_64KB: "y"
      CONFIG_ESP32_DATA_CACHE_LINE_64B: "y"
      CONFIG_ESP32S3_DEFAULT_CPU_FREQ_240: "y"
      CONFIG_ESP32S3_DEFAULT_CPU_FREQ_MHZ: "240"
      CONFIG_ESP32S3_DATA_CACHE_64KB: "y"
      CONFIG_ESP32S3_DATA_CACHE_LINE_64B: "y"

external_components:
  - source:
      type: git
      url: https://github.com/ssieb/custom_components
    components: [ serial ]

logger:
  level: VERBOSE
  baud_rate: 115200

api:
  encryption:
    key: !secret api_encryption_key

ota:
  password: !secret ota_password
  safe_mode: false

web_server:
  port: 80
  auth:
    username: !secret web_auth_username
    password: !secret web_auth_password

wifi:
  ssid: !secret wifi_ssid
  password: !secret wifi_password
  domain: !secret wifi_domain
  power_save_mode: LIGHT
  reboot_timeout: 5min

uart:
  id: LD1125H_UART_BUS
  rx_pin: GPIO18
  tx_pin: GPIO19
  setup_priority: 200
  baud_rate: 115200
  data_bits: 8
  stop_bits: 1
  parity: NONE

i2c:
  sda: GPIO21
  scl: GPIO22
  scan: true

#
# Radar Globals
#
globals:
  - id: LD1125H_Last_Update_Time
    type: uint32_t
    restore_value: no
    initial_value: millis()
  - id: LD1125H_Last_Time
    type: time_t
    restore_value: no
    initial_value: time(NULL)
  - id: LD1125H_Last_Mov_Time
    type: time_t
    restore_value: no
    initial_value: time(NULL)
  - id: LD1125H_Clearance_Status
    type: bool
    restore_value: no
    initial_value: "false"
  - id: ignored_ranges
    type: std::vector<std::vector<float>>
    restore_value: no
    initial_value: ${ignored_radar_ranges}

#
# Voice Control
#
i2s_audio:
  i2s_lrclk_pin: GPIO25
  i2s_bclk_pin: GPIO26

microphone:
  - platform: i2s_audio
    id: mic
    adc_type: external
    i2s_din_pin: GPIO27
    pdm: false
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

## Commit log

2023-11-22 Adjust time, remove superflous sensors
2023-11-22 Improve wake word error issues
    [supersensor.yaml]
2023-11-23 Use while loop for pir_holdtime
    Ensures that the time keeps extending as long as the sensor is firing.
2023-11-23 Fix bad ordering on error
    [supersensor.yaml]
2023-11-24 Readd second turn_off
    Sometimes the LED gets stuck without this
    [supersensor.yaml]
2023-11-27 Readd client disconnect restart and readjust noise
    [supersensor.yaml]
2023-12-05 Add trial HLK sensors
2023-12-05 Fix gain on light sensor
    [supersensor.yaml]
2023-12-06 Add full presence mode sensor and light presence
2023-12-07 Adjust TSL sensor names
2023-12-07 Adjust TSL sensor configuration
2023-12-10 Set device class of LD2410C presence
2023-12-10 Fix bad copypasta conditional detections
    [supersensor.yaml]
2023-12-15 Add BME680, fix LEDs
    [supersensor.yaml]
2023-12-16 Revert to no-transistor config
    [supersensor.yaml]
2023-12-16 Switch to BME680 BSEC version
    The IAQ is useless out of the default, so switch to the Bosch library,
    even if it's proprietary.
    Requires switching back to Arduino instead of ESP-IDF but so far through
    many tests this hasn't been a big deal.
2023-12-16 Fix icon for LD2410C Presence
    [supersensor.yaml]
2023-12-16 Track both BSEC and non-BSEC versions
2023-12-16 Fix restarting and starting voice_assistant
    [supersensor.yaml]
2023-12-16 Revert "Move API checking to interval"
    This reverts commit d98619b1e43cdcfb0aae059452edcb2ccd0bfc19.
    [supersensor.yaml]
2023-12-16 Revert "Fix restarting and starting voice_assistant"
    This reverts commit 09e76eb8d0ee4e97d1a3cdf12302ab0cb3c1b2ed.
    [supersensor.yaml]
2023-12-16 Revert "Add interval recovery"
    This reverts commit 68dfd8529e77207fa1d12e6d75a26ea012fe5e7b.
    [supersensor.yaml]
2023-12-17 Add logging and more VA cleanup/fixes
    [supersensor.yaml]
2023-12-23 Adjust volume and noise suppression levels
    [supersensor.yaml]
2024-04-23 Remove secret sample and add ignore of override
2024-04-23 Add board definitions
    [supersensor.dxf]
2024-06-06 Set median filters for BME values
2024-06-06 Add ESP32 factory reset button
2024-06-09 Fix m to min
    [supersensor.yaml]
2024-06-10 Adjust timeout and output power of WiFi
2024-06-11 Switch from BSEC to normal BME680
    The BSEC module causes failures in determining the IAQ value due to its
    opaque and nonsensical "calibration" routines. Switch back to manual
    calculation.
    [supersensor.yaml]
2024-06-11 Implement improved AQ calculation
    Implements an AQ calculation from [1], which should hopefully provide a
    more stable, sensible value for the air quality.
    This also adds a configurable gas ceiling level, needed for full
    calibration and explained in the README.
    [1] https://github.com/thstielow/raspi-bme680-iaq
    The human text ratings are still a work-in-progress.
2024-06-11 Improve gas_ceiling scaling
    Represent int kΩ rather than raw Ω for easier values.
2024-06-11 Update ceiling name
    Make it clearer this is the resistance ceiling.
2024-06-11 Fix unit of Illumination sensor
    [supersensor.yaml]
2024-06-14 Adjust oversamping and IIR filter
2024-06-14 Increase iir filter value
2024-07-04 Go back to esp-idf
    This seems to perform a lot better, and now that we're not using the
    official Bosch sensor libraries, this is fine.
2024-07-12 Revert "Further adjust VA restarting"
    This reverts commit 0e142fa8dde9ca0fbd9114844ae7156380ba4981.
    [supersensor.yaml]
2024-07-12 Add restart after error
    [supersensor.yaml]
2024-07-13 Rework the status again
    [supersensor.yaml]
2024-09-16 Remove VAD threshold and lower noise suppression
    [supersensor.yaml]
2025-01-15 Fix IDF builds in 2024.12
    [supersensor.yaml]
2025-02-07 Return to arduino and try bsec2 library
2025-02-09 Revert "Fix incorrect names"
    This reverts commit 07c15f60b4767d9726da791dc987770c82e977c4.
    [supersensor.yaml]
2025-02-09 Revert previous BSEC2 changes
    This library proved to be just as useless for reliable IAQ as the
    original BSEC library (swinging wildly based on nothing at all), so
    revert back to tag 1.2 and ESP-IDF.
    [supersensor.yaml]
2025-02-18 Add more light off conditions
    Hopefully fixes stuck cyan light after VAD errors.
    [supersensor.yaml]
2025-02-22 Revert "Add more light off conditions"
    This reverts commit 414de937e14b7799b679e27331cb6eee2dca2de3.
    [supersensor.yaml]
2025-02-25 Add LED presence indication support
    Adds a mode where the lights will be on "white" at 15% when presence is
    detected. May be enabled or disabled from a new switch component.
2025-02-25 Improve STT response handling
    Newer versions of HASS provide different error messages than just the
    previous one, so match any that begin with Sorry for errors. Also log
    the response (INFO level) so we can see it.
    [supersensor.yaml]
2025-02-25 Return to 1s transitions
    2s just felt too long.
    [supersensor.yaml]
2025-02-26 Add temperature offset support
    Allows user configuration of a temperature offset for the BME680 sensor,
    to help mitigate the effects of external heating from the ESP32, an
    encosure, or other factors. A range of -7 to 3 is provided to permit
    flexibility while recognizing that in *most* cases, it will be negative.
2025-02-26 Raise BME680 update interval to 15s
    Temperature doesn't swing that wildly.
    [supersensor.yaml]
2025-02-26 Add comment for temperature offset
2025-03-16 Round illumination value to 1 decimal
    Avoids constant updates to HASS that are useless.
    [supersensor.yaml]
2025-03-20 Apply optimizations for state updates
    Have been running into issues with states not being updated properly.
    Apply several optimizations to help improve this.
    [supersensor.yaml]
2025-03-20 Attempt to fix bugs with voice on startup
    [supersensor.yaml]
2025-04-01 Add utemp (micro temperature) sensor
2025-04-01 Add temperature offset to utemp
2025-04-02 Adjust utemp calibration values
2025-04-04 Add IRR filter to utemp
2025-04-21 Round pressure to int, add pressure offset, names
    Helps ensure barometric pressure is accurate against a given reference
    value and ensure names are grouped together.
2025-04-21 Set pressure accuracy decimals
    Since we're rounding to an integer now.
2025-04-24 Add relative pressure calculations
2025-04-24 Round final value of relative pressure
2025-04-24 Restore 1 decimal place to pressure values
    Let the frontend round if it wants to.
2025-05-11 Enable MicroWakeWord by default.
    This enables MWW by default. This has become more important since
    HomeAssistant recently disabled offloaded WakeWord engines by default in
    new Assist pipelines, ostensibly because "all" client devices now
    support it.
    Currently we are limited to just `hey_jarvis` until esphome/esphome#8655
    lands in a release and enables dynamic configuration. This will be fully
    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
2025-12-01 Refactor LED flow based on state machine
    This method eliminates the previous edge cases where an LED response
    would be incorrectly superseded by other events, specifically idle
    presence status events, or a hold superseding a newer pipeline event.
    This new method uses a 3 priority state machine to correctly determine
    which updates are valid and should supersede which others, while also
    moving the LED colour determination to a substate based on the actual
    function.
    * 0 represents idle state, where nothing else is happening; the LEDs can
    either be off or on dim white for presence in this state.
    * 1 represents hold state, where an LED is being held for a fixed 5s
    duration.
    * 2 represents p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
    [supersensor.yaml]
2025-12-05 Add LED brightness control options
    Adds configurable brightness settings for the various LED states to
    provide more user control over the experience here.
2025-12-05 Fix incorrect brightness handling
    [supersensor.yaml]
2025-12-10 Add additional LD2410C sensors and configuration
    1. Add individual gate sensors for debugging.
    2. Add force-refresh button.
    3. Add auto-calibration button courtesy of esauvisky on HASS forums.
2025-12-10 Fix sensor names
2025-12-10 Adjust gate threshold sensor names
    Ensure consistency with the engineering value sensors and save space.
2025-12-10 Revert "Add separate IDs for consistent internal naming"
    This reverts commit 05c61ea07baa2b59a7d64db89c389822fc1733be.
    This didn't work how I wanted. Annoying that they will change but nicer
    for overall use.
    [supersensor.yaml]
2025-12-16 Revert "[testing] Increase gain factor further to 64"
    This reverts commit 9b84a90c2e539e18531ba6a5bd84159bdf27bcee.
    [supersensor.yaml]
2025-12-16 Revert "Raise gain of MWW microphone"
    This reverts commit bf57b1e7e29a02632dcbd749c850ac4048ece98e.
    [supersensor.yaml]
2026-01-03 Adjust LD2410C calibration to 300s
    60s was far too short in my experience, and could miss transient events
    that would be more likely to happen with a longer interval. Thus, we use
    300s instead which provides a much more robust time slice.
    [supersensor.yaml]
2026-01-03 Fix invalid values for LD2410C calibration
    [supersensor.yaml]
2026-01-29 Add LED state handlers for end and idle
2026-02-15 Add LD2410C restart on boot
    Helps avoid flaky LD2410C startup issues on recent ESPHome.
    [supersensor.yaml]
2026-03-19 Update ESPHome to 2026.3.0, new dew_point sensor
2026-03-19 Remove v2.x board and case
    [am312-tube.obj, body.obj, face.obj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]
2026-03-19 Update README, board, and case for v3.x
    [case-body.obj, case-cover.obj, case-insert.obj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]
2026-06-06 Improve calibration routine for LD2410C
    The previous calibration routine provided no live status and accepted
    the calibration outputs as-is, and was also relatively short.
    Improve this significantly by:
    * Increasing the run time to 900s instead of 300s
    * Adding status reporting of the run
    * Moving the calibration routine to a script to prevent double-triggers
    * Adding automatic +2 value calibration to all gate sensors once
    finished
    * Adding error handling if the LD2410C fails somehow
    * Bypassing the 30s liveliness check during calibration (just in case)
    [supersensor.yaml]

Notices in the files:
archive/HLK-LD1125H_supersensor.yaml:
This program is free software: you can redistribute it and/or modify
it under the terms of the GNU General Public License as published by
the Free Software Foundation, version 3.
